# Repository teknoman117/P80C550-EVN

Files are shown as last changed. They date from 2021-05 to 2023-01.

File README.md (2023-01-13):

P80C550-EVN (Rev 1.01)
====================

The P80C550-EVN is a small 8051 single board computer designed around the notion of sourcing the major components from the random collection of electronics I've accumulated over the years. It started as a breadboard computer I built after being inspired to resume my electronics hobby after watching Ben Eater's YouTube series. After carting the breadboard computer around enough for the wires to start randomly loosening, I figured I might as well make a proper PCB for the project.

Features
--------
- CPU: P80C550 @ 11.0592 MHz
- 32 KiB ROM
- 32 KiB SRAM
- Expansion Bus
- HD44780 LCD connector
- 8x 8 bit ADC channels (from CPU)
- AM85C30 Dual UART or SDLC controller
- PCF8584 I2C controller
- MC146818 RTC and RAM with battery backup
- Runs off 5V, or 7V to 18V
- Configurable battery saver with CPU interrupt

Revision History
----------------
Revision 1.0
  - First Board Produced
  - Design and/or Production Errors
    - MAX693 RST signal (active-high) is open collector. This was not mentioned in the chip's datasheet, therefore no pull-up was designed into the board. [#1](https://github.com/teknoman117/P80C550-EVN/issues/1)
    - MAX693 ~RST signal (active-low, wired-OR) does not propagate to RST (active-high). Pushing the reset button will reset only the peripherals and not the CPU. [#2](https://github.com/teknoman117/P80C550-EVN/issues/2)

Revision 1.01
  - Disconnects the non-inverted RST signal from the MAX693
  - Add BSS84 P-Channel MOSFET to invert the ~RST signal. The P80C550 has an internal 50k to 300k pulldown resistor and the ~RST signal is current limited, so no additional components are required other than the MOSFET.

The Hardware
============

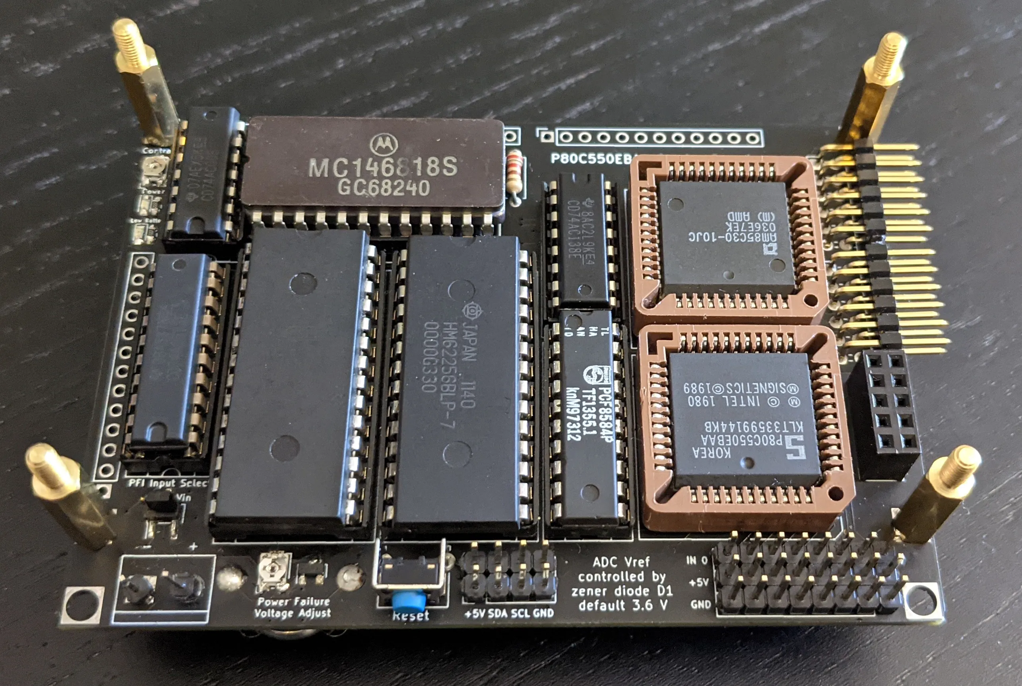
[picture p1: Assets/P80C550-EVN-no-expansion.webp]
Assembled Without Expansion Headers


## Processor

The CPU is a ROM-less CMOS 8051 microcontroller made by Signetics in the late 1980's. The only major differences from the original are that the Signetics part integrates an 8 bit analog to digital converter (with an 8 channel mux on Port 1), a programmable watchdog timer, and is built on a CMOS process. By nature of being ROM-less, the majority of the I/O ports must be used for the external bus interface (Port 2 = A8..15, Port 0 = AD0..7, Port 3.6 and 3.7 are the ~RD and ~WR signals). This is both good and bad, as we must use extra chips to get GPIO functions, but allows us to use far more than the 2K/4K/8K of ROM the 8051 could be ordered with and the 128 bytes of internal RAM. You can also use EEPROM or Flash for code storage, which is much nicer than needing to pick up an EPROM eraser.

## Memory Map

The memory for the board is provided via two 28 pin JEDEC compliant memory sockets supporting up to 32 KiB each. The left socket is for the ROM and the right socket is for the external data memory. Typically, an SRAM would be installed into the data socket, but this could also be a ROM or Flash device (such as AT29Cxx) if memory beyond the 128 byte internal RAM and 50 byte RTC/CMOS RAM is not required. Both sockets are mapped in the lower half of their respective address spaces (ROM in lower 32 KiB of CODE memory and the RAM in the lower 32 KiB of XDATA memory).

The onboard peripherals are mapped in the 8 KiB of address space following the XDATA memory as 1 KiB chunks. This may seem wasteful, but it allows using a single '138 3-to-8 decoder for peripheral chip selects (active high enable is A15, active low enables are A14 and A13. A12 -> A10 are then used for the select input).

| Code Address | Description |
| --- | --- |
| 0000h -> 7FFFh | 32 KiB ROM socket (by default - see [Expansion](#expansion)) |
| 8000h -> FFFFh | **unused**  |

| Data Address | Description |
| --- | --- |
| 0000h -> 7FFFh | 32 KiB XDATA socket |
| 8000h | [Power Status Register](#power-status-register) |
| 8400h -> 8FFFh | **unused** |
| 9000h -> 903Fh | [RTC](#rtc) |
| 9400h -> 9403h | [UART / SDLC](#uart--sdlc) |
| 9800h -> 9801h | [I2C controller](#i2c) |
| 9C00h -> 9C01h | [LCD](#lcd) |
| A000h -> FFFFh | **unused** |

## Interrupts

The P80C550 has two external interrupt lines which can either be falling edge triggered or low level triggered. There is an internal pullup resistor on the CPU and peripherals with open collector interrupt outputs can be wire-OR'd together on the same interrupt line.

| Interrupt | Devices |
| --- | --- |
| EX0 | Power Fault, RTC, I2C  |
| EX1 | UART / SDLC |

## Power and Battery Saver

The board can either be powered directly via the 5V rail, or by a 7V to 18V terminal block, which is regulated to 5V by an AP62150WU-7 buck regulator. The input voltage range means the board can be safely powered by
- 5 to 12 AA(A) batteries
- 6 to 12 cell NiMH batteries
- 2 to 4 cell Li-ion or Li-Poly batteries

There is also a holder for an *optional* CR1216, CR1220, or CR1225 3V coin cell to power the RTC. If omitted, RTC and CMOS state will be lost on power-off. A CR1216 is good for at least 2 months (and counting).

A MAX693 microprocessor supervisor is used to manage the power-on reset delay, the RTC backup power, a low power fault signal, and provide 5V rail undervoltage protection.

A potentiometer is provided to configure the low power threshold. A jumper ("PFI Input Select") is provided to select whether the source voltage is provided from the Vin terminal block or the 5V rail. The former is used in battery powered or other scenarios using the input regulator and the latter is used when the 5V rail is directly driven. A 5.1V zener diode protects from accidental overvoltage on the voltage reference inputs.

The MAX693 will report a low power fault when the reference input drops below **1.3V**. By default, this will trigger the EX0 interrupt on the P80C550. A single bit register ([Power Status Register](#power-status-register)) is provided to check the status of the power fault output of the MAX693 and to mask the interrupt it generates.

For scenarios directly powering the 5V rail, the voltage divider should be configured to output 1.444V at 5V. This will trigger the lower power fault if the rail drops to 4.5V, which is the minimum safe CPU operating voltage. The MAX693 will hold the CPU in a reset state if the 5V rail drops further to 4.4V.

In Vin powered scenarios, the AP62150WU-7 buck regulator will shut down when the reference input drops below **1.2V** and completely cut power to the board. The voltage divider should be configured such that power is cut when the voltage drops to the minimum voltage of your battery, or the minimum voltage of the regulator (about 6.5V).

To determine the output voltage of the voltage divider at a specific input voltage given a target cutoff voltage, use the following formula:

 > Vout = Vin * (1.2V / Vcutoff);

Vin is the current input voltage and Vcutoff is the desired voltage for the regulator to shut off. Vout is the voltage that the voltage divider should be configured to output at that input voltage. See the example configurations below. The emphasis on maximum voltages is to ensure you are aware that "fresh off the charger" batteries have a notably higher voltage than their nominal voltage (which they will drop to quickly), so be aware of this when tuning the cutoff reference.

### Example Voltage Divider Configurations
- Directly powering the 5V rail
  - PFI Input Select: 5V rail
  - Vcutoff = 4.5V (minimum **cpu** voltage)
  - Vout = **5V** * (1.3V / 4.5V) = 1.444V
    - Low Power Fault at 4.5V on 5V rail
    - CPU held in reset at 4.4V on 5V rail

- Li-Ion or Li-Poly Batteries (per cell: 4.2V maximum, 3.7V nominal, and 3.0V minimum)
  - PFI Input Select: Vin
  - 2 cell battery (8.4V maximum, 7.4V nominal, 6V minimum)
    - Vcutoff = 6.5V (minimum **regulator** voltage)
    - Vout = **8.4V** * (1.2V / 6.5V) = 1.550V
    - Vout = **7.4V** * (1.2V / 6.5V) = 1.366V
      - Low Power Fault at 7.04V on Vin (~12% charge)
      - Power cutoff at 6.5V on Vin (~7% charge)
  - 3 cell battery (12.6V maximum, 11.1V nominal, 9V minimum)
    - Vcutoff = 9V (minimum **battery** voltage)
    - Vout = **12.6V** * (1.2V / 9V) = 1.680V
    - Vout = **11.1V** * (1.2V / 9V) = 1.480V
      - Low Power Fault at 9.75V on Vin (~7% charge)
      - Power cutoff at 9V on Vin (~5% charge)
  - 4 cell battery (16.8V maximum, 14.8V nominal, 12V minimum)
    - Vcutoff = 12V (minimum **battery** voltage)
    - Vout = **16.8V** * (1.2V / 12V) = 1.680V
    - Vout = **14.8V** * (1.2V / 12V) = 1.480V
      - Low Power Fault at 13V on Vin (~7% charge)
      - Power cutoff at 12V on Vin (~5% charge)

- NiMH Batteries (per cell: 1.5V maximum, 1.2V nominal, and 1.0V minimum)
  - PFI Input Select: Vin
  - 7 cell battery (10.5V maximum, 8.4V nominal, 7.0V minimum)
    - Vcutoff = 7V (minimum **battery** voltage)
    - Vout = **10.5V** * (1.2 / 7V) = 1.800V
    - Vout = **8.4V** * (1.2 / 7V) = 1.440V
      - Low Power Fault at 7.58V on Vin (~5% charge)
      - Power cuttoff at 7V on Vin (~0% charge)

### Power Status Register
- Address: 8000h
- Read: Bit 7 is the ~PFO (Power Fault) line from the MAX 693 Supervisor
  - 0 = Low Voltage
  - 1 = Nominal Voltage
- Write: Bit 7 is the ~PFO (Power Fault) interrupt mask
  - 0 = Enable PFO interrupt
  - 1 = Disable PFO interrupt
- Bits 0 -> 6 undefined

## UART / SDLC

The AM85C30 "Enhanced Serial Communications Controller" can function as a UART or as an SDLC/HDLC controller. In UART mode, there is a 3 byte RX FIFO, but no TX FIFO. The SDLC/HDLC mode adds a 10 entry frame status FIFO, but the data FIFOs remain the same. The chip is intended to be used with a DMA engine, but this does not exist on the 8051 platform. If a deeper FIFO is required, there is a more modern (less old?) drop-in compatible version available called the Z85230, which appears to still in production. It adds a 4 byte TX FIFO and increases the RX FIFO to 8 bytes from 3 bytes.

| Data Address | Description |
| --- | --- |
| 9400h | Channel B - Control |
| 9401h | Channel B - Data |
| 9402h | Channel A - Control |
| 9403h | Channel A - Data |

## I2C

The PCF8584 is an I2C controller supporting a 100 KHz SCL frequency in either master or slave mode.

| Data Address | Description |
| --- | --- |
| 9800h | Register Access  |
| 9801h | Control |

## RTC

The RTC is the classic MC146818 chip that was present in the PC/AT that defined the pinout and register layout that later parts such as the Dallas DS1285, DS12885, and DS1685 use. No special battery input, no integrated oscillator, etc. The MAX693 is used to avoid needing the diode setup specified in the manual. 

| Data Address | Description |
| --- | --- |
| 9000h | Seconds |
| 9001h | Seconds (Alarm) |
| 9002h | Minutes |
| 9003h | Minutes (Alarm) |
| 9004h | Hours |
| 9005h | Hours (Alarm) |
| 9006h | Day of Week |
| 9007h | Day of Month |
| 9008h | Month |
| 9009h | Year |
| 900Ah | Register A |
| 900Bh | Register B |
| 900Ch | Register C |
| 900Dh | Register D |
| 900Eh -> 903Fh | 50 bytes of Battery Backed RAM |

## LCD

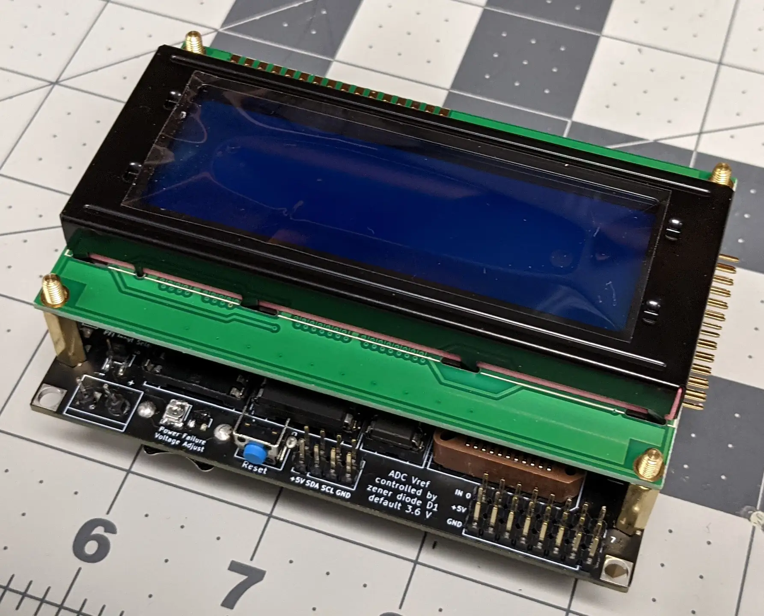
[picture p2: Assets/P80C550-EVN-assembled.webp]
Assembled With LCD


Any LCD module compatible with the 16 pin HD44780 header may be used. The mounting holes are spaced for the popular LCD2004A module (20x4 characters) that can be found pretty much everywhere.

| Data Address | Description |
| --- | --- |
| 9C00h | LCD - Control |
| 9C01h | LCD - Data |

## PCB
| Front Side | Back Side |
| --- | --- |
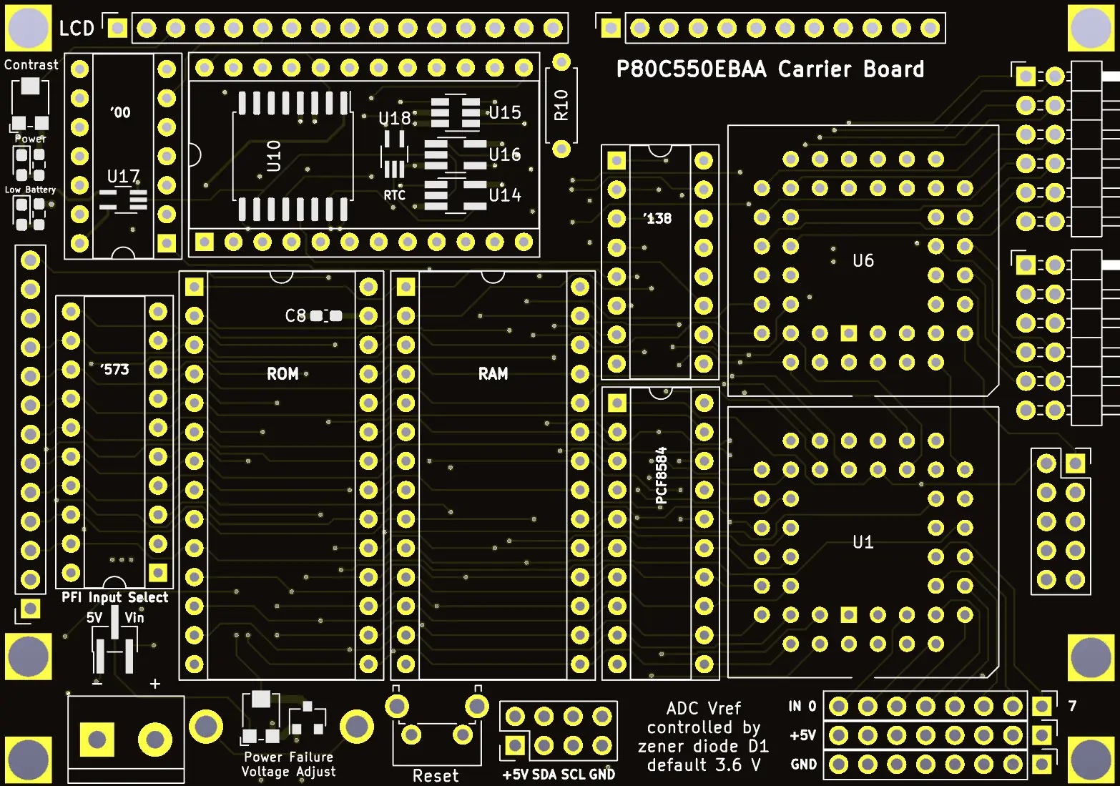
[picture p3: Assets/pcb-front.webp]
Front
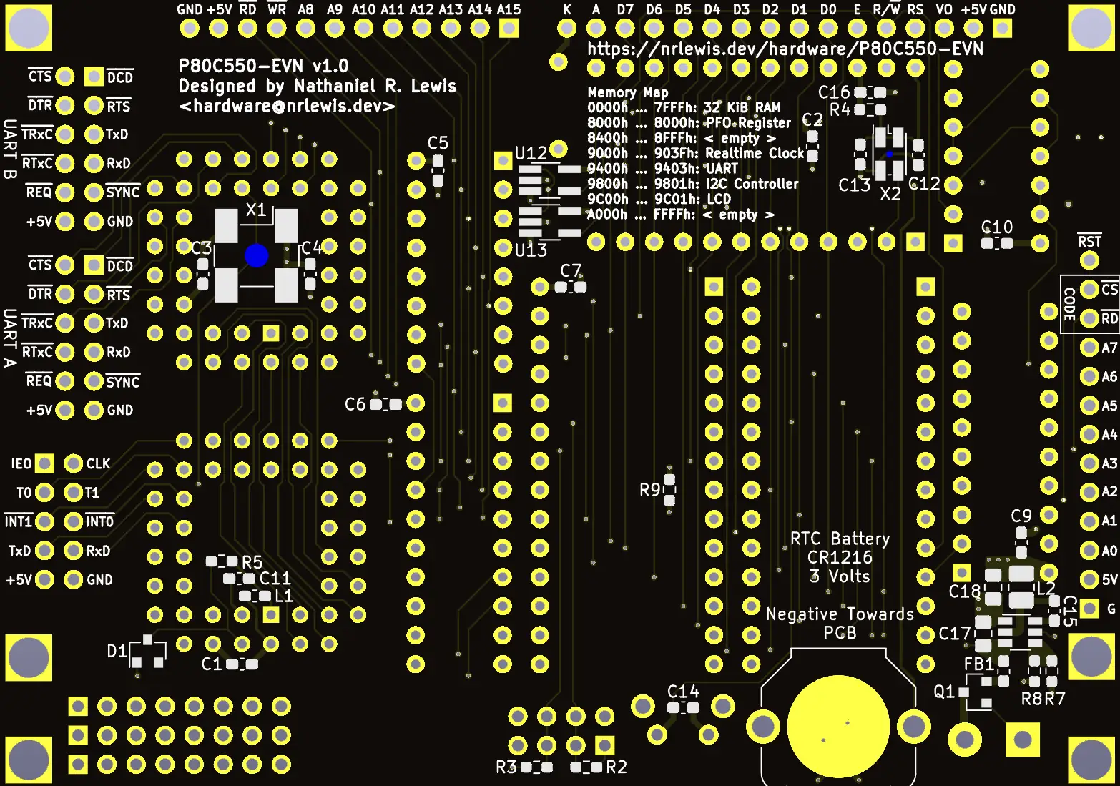
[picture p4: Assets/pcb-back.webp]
Back
|  |  |

| Layout (Power Planes Not Shown) |
| ---------------------------------- |
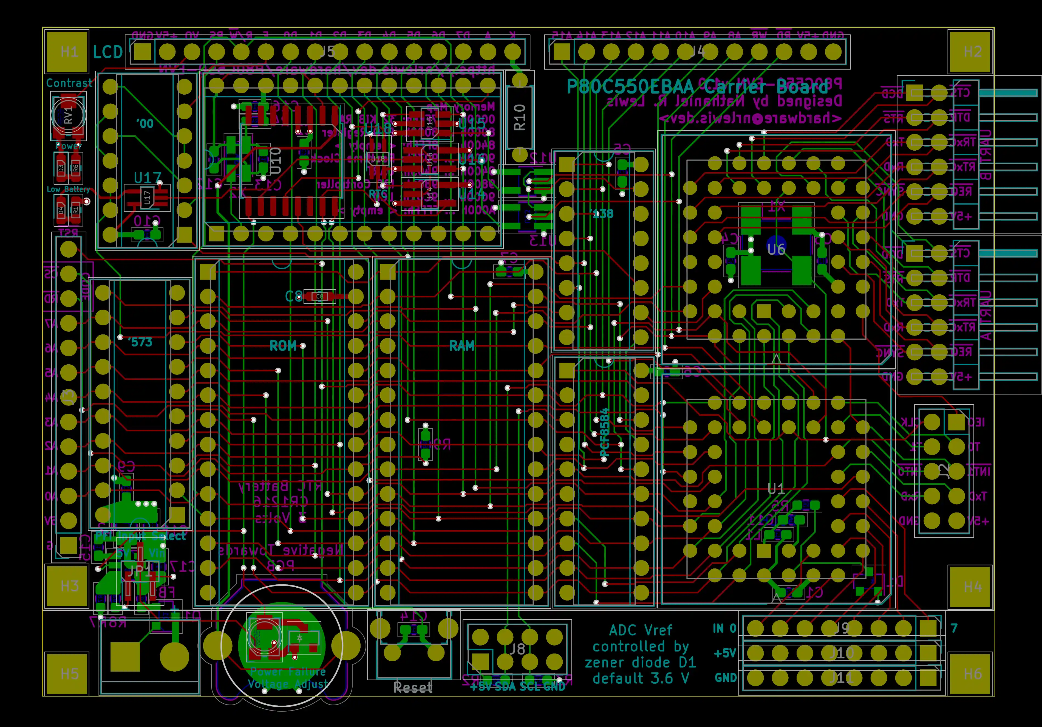
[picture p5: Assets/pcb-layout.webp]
Layout
|  |

The PCB is a 98 mm by 69 mm, 4-layer board (2 signal layers, one +5V plane, and one ground plane) following the design rules for the low cost JLCPCB 4-layer process. Using 4 layers made the routing far easier, as I didn't have to worry about getting power in and around all of the signal traces. At time time of writing, 5 boards using Leaded HASL and a green PCB material is $8 (USD). Switching to ENIG-RoHS increases the price to $23.40 (USD) for 5 boards. 10 boards is $29 (USD), as they seemingly charge a flat rate for switching to ENIG on small orders. I also opted for FR4 TG155 because it's more tolerant to hot air soldering.

To order, you can contact me at [hardware@nrlewis.dev](mailto:hardware@nrlewis.dev) and see if I have any laying around, or you can send the gerber files (attached to release tags) to your board house of choice. JLCPCB is my recommendation, as it seems that they have a lower 4-layer board tier available. PCBWay seems good as well, but their 4-layer process is a bit overkill for this board.

The smallest components on the PCB are 0603 passives. These are the smallest size I'm comfortable hand soldering. Call me crazy, but I assembled this whole board using a Weller WE1010NA soldering station with a (small point) chisel tip, flux core solder, a flux pen, some solder wick, and a pair of tweezers from an iFixit kit. Apply flux generously, hold the components onto the pads with tweezers, hold your breath, and apply solder.

## Expansion

All of the major bus signals are broken out to stackable headers to allow for stacked expansion boards.

### ROM Expansion

The ROM read signal (~CODE_RD) and chip select (~CODE_CS) are broken out to the address low-byte header. The ~CODE_CS pin has a pulldown to keep the ROM enabled when no expansion boards are installed. The main idea behind these signals is to enable the creation of a self-programming expansion. By default, the ROM socket occupies both the lower and upper 32 KiB of the code address space, as the chip select is always enabled and A15 is ignored. A self programming module would allow the onboard ROM be either relocated or disabled when switching to an external memory.

#### Address Low-Byte Header

| Pin | Description |
| --- | --- |
| 1 | GND |
| 2 | +5V |
| 3 | A0 |
| 4 | A1 |
| 5 | A2 |
| 6 | A3 |
| 7 | A4 |
| 8 | A5 |
| 9 | A6 |
| 10  | A7 |
| 11  | ~CODE_RD |
| 12  | ~CODE_CS |
| 13  | ~RST |

#### Address High-Byte Header

| Pin | Description |
| --- | --- |
| 1 | A15 |
| 2 | A14 |
| 3 | A13 |
| 4 | A12 |
| 5 | A11 |
| 6 | A10 |
| 7 | A9 |
| 8 | A8 |
| 9 | ~WR |
| 10  | ~RD |
| 11  | +5V |
| 12  | GND |

#### LCD Header

| Pin | Description  |
| --- | --- |
| 1 | GND |
| 2 | +5V |
| 3 | LCD_VO |
| 4 | A0 |
| 5 | ~WR |
| 6 | LCD_E |
| 7 | D0 |
| 8 | D1 |
| 9 | D2 |
| 10  | D3 |
| 11  | D4 |
| 12  | D5 |
| 13  | D6 |
| 14  | D7 |
| 15  | LCD_A (+5V)  |
| 16  | LCD_K |

#### CPU Peripheral Header

| Pin | Description |
| --- | --- |
| 1 | UART_IEO |
| 2 | CLK (11.0592 MHz) |
| 3 | P3.4 - T0 |
| 4 | P3.5 - T1 |
| 5 | P3.3 - ~INT1 |
| 6 | P3.2 - ~INT0 |
| 7 | P3.1 - TxD |
| 8 | P3.0 - RxD |
| 9 | +5V |
| 10  | GND |

#### ADC Header

| Pin | Description  |
| --- | --- |
| 1 | P1.0 (ADC 0) |
| 2 | P1.1 (ADC 1) |
| 3 | P1.2 (ADC 2) |
| 4 | P1.3 (ADC 3) |
| 5 | P1.4 (ADC 4) |
| 6 | P1.5 (ADC 5) |
| 7 | P1.6 (ADC 6) |
| 8 | P1.7 (ADC 7) |

#### UART Headers

| Pin | Description |
| --- | --- |
| 1 | DCD |
| 2 | CTS |
| 3 | RTS |
| 4 | DTR |
| 5 | TX |
| 6 | TX Clock |
| 7 | RX |
| 8 | RX Clock |
| 9 | SYNC |
| 10  | REQ |
| 11  | GND |
| 12  | +5V |

## Datasheets

[P80C550EBAA - DigChip](https://www.digchip.com/datasheets/download_datasheet.php?id=741162&part-number=P80C550EBAA)

[MAX693 - Maxim](https://datasheets.maximintegrated.com/en/ds/MAX690-MAX695.pdf)

[AM85C30 (1) - ChipDB](http://datasheets.chipdb.org/AMD/07513.pdf)

[AM85C30 (2) - Rockby](https://www.rockby.com.au/DSheets/26719.pdf)

[PCF8584 - NXP](https://www.nxp.com/docs/en/data-sheet/PCF8584.pdf)

[MC146818 - NXP](https://www.nxp.com/docs/en/data-sheet/MC146818.pdf)

[LCD2004A - Beta-eStore](https://www.beta-estore.com/download/rk/RK-10290_410.pdf)

## Background

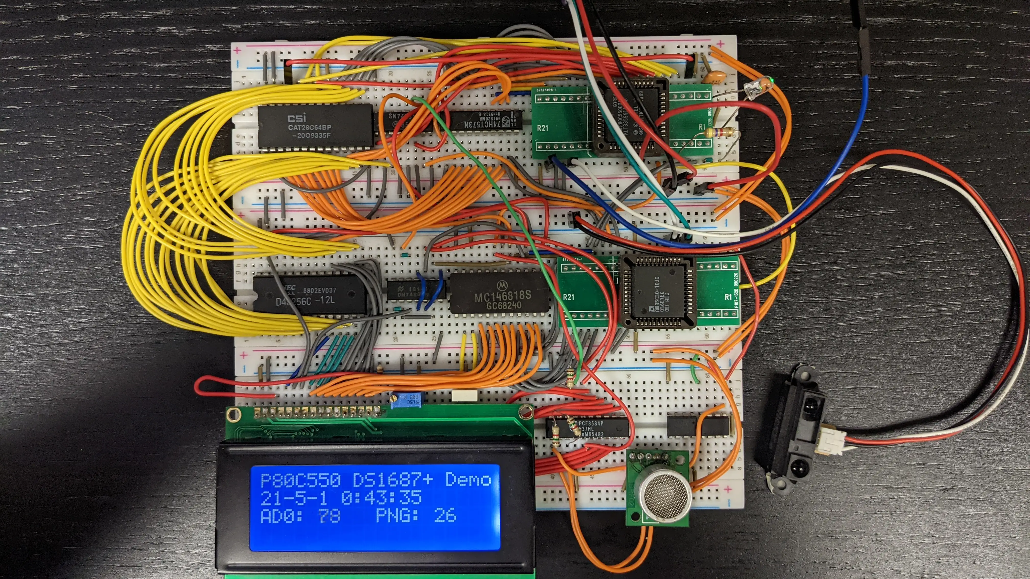
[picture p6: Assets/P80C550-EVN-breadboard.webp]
Breadboard Computer


The design goal was for the major components to be sourced from the collection of random electronics I've accumulated over the years - hence a board built around archaic parts newly created in 2021.

The peripherals are straight out of a 1980's PC builder's kit. I think it was 2003 when I received the core parts of this board. I was a member of Chibots in Chicago as a kid and I picked them up during the regular "I'm not taking this back home with me" parts dump / swap meet at the end of club meetings. I ended up with a tubes of 8051 controllers, MAX693 microprocessor supervisors, AM85C30 Dual UARTs / SDLC / HDLC controllers, MC146818 RTC/RAMs (used on PC/AT), and some engineering sample RS232 to TTL level shifters (XC prefix Motorola parts). I have to imagine the person who gave them to me had to have built a board along these lines sometime in the past. Probably with these components. I bet they didn't have the luxury of dirt-cheap 4 layer PCBs though and open source EDA tools :).

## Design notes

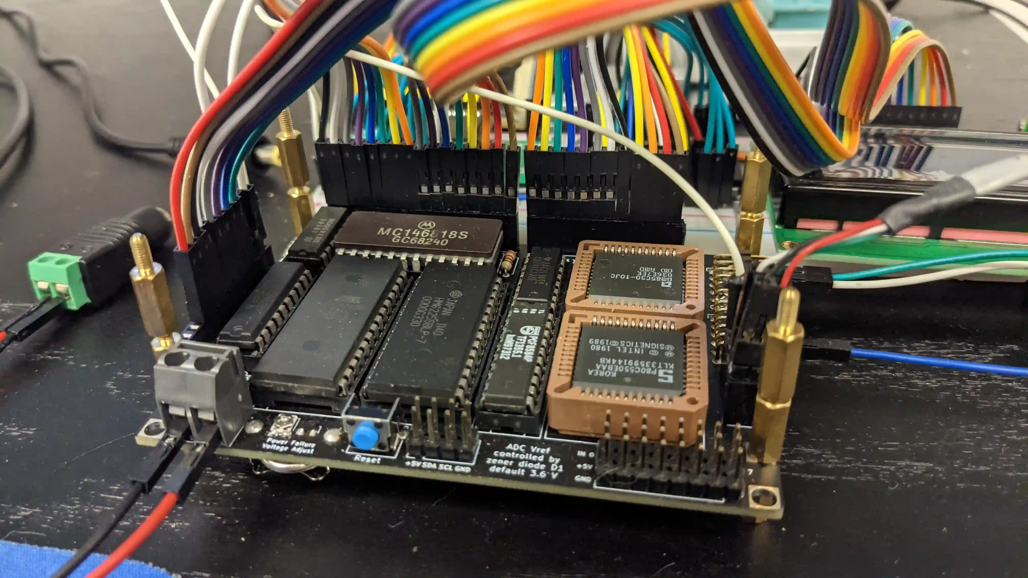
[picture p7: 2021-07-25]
Assets/P80C550-EVN-expansion.webp

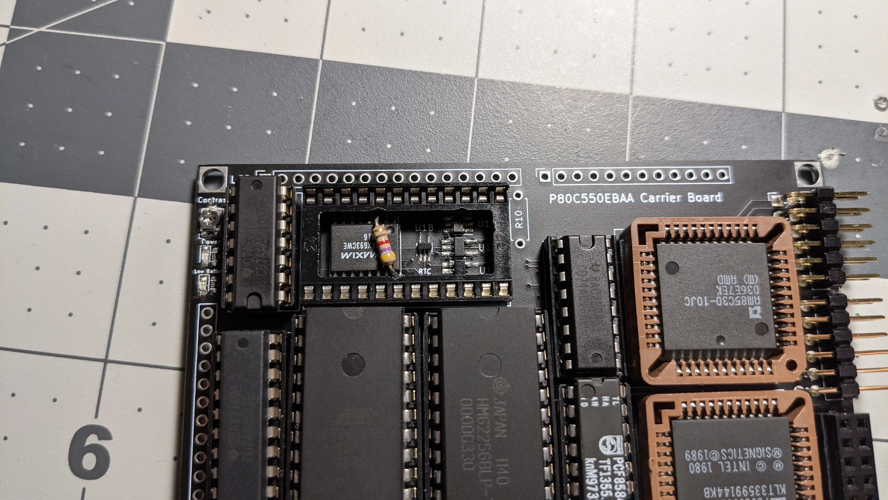
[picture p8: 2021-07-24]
Assets/P80C550-EVN-reset-bodge.webp

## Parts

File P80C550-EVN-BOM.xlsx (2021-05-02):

Component | Quantity | Quantity 5x | Part Name | Digikey Part Number | Digikey Website Link | Manufacturer Part Number
BT1 | 1 | 5 | RTC Backup | 36-3001-ND‎ | https://www.digikey.com/product-detail/en/3001/36-3001-ND/227442 | 3001
C16 | 1 | 5 | 5.1nF | 478-06033C512JAT4ACT-ND | https://www.digikey.com/en/products/detail/avx-corporation/06033C512JAT4A/1599493 | 06033C512JAT4A
C17 | 1 | 5 | 10uF | 587-2985-1-ND | https://www.digikey.com/en/products/detail/taiyo-yuden/TMK212BBJ106KG-T/2714163 | TMK212BBJ106KG-T
C18 | 1 | 5 | 22uF | 587-5464-1-ND | https://www.digikey.com/en/products/detail/taiyo-yuden/LMK212BBJ226MG-T/7067049 | LMK212BBJ226MG-T
C1 C2 C3 C4 C5 C6 C7 C8 C9 C10 C11 C12 C13 C14 C15 | 15 | 75 | 0.1uF | 445-1316-1-ND‎ | https://www.digikey.com/product-detail/en/C1608X7R1E104K080AA/445-1316-1-ND/567697 | C1608X7R1E104K080AA
D1 | 1 | 5 | 3.6V (zener) | 1727-5033-1-ND‎ | https://www.digikey.com/product-detail/en/BZX84-C3V6%2c215/1727-5033-1-ND/2531614 | BZX84-C3V6,215
D1 (alt) | 1 | 5 | 3.3V (zener) | 1727-2129-1-ND | https://www.digikey.com/en/products/detail/nexperia-usa-inc/BZX84-C3V3-235/1156089 | BZX84-C3V3,235
D2 | 1 | 5 | 5.1V (zener) | 1727-2130-1-ND‎ | https://www.digikey.com/product-detail/en/BZX84-C5V1%2c235/1727-2130-1-ND/5221774/?itemSeq=362662134 | BZX84-C5V1,235
D3 | 1 | 5 | Blue | ‎1830-1068-1-ND‎ | https://www.digikey.com/product-detail/en/IN-S63BT5B/1830-1068-1-ND/7604710 | IN-S63BT5B
D4 | 1 | 5 | Yellow | 1830-1072-1-ND‎ | https://www.digikey.com/product-detail/en/IN-S63BTR/1830-1072-1-ND/7604714 | IN-S63BTR
FB1 | 1 | 5 | 100 @ 100 MHz | 587-1738-1-ND‎ | https://www.digikey.com/product-detail/en/FBMH1608HM101-T/587-1738-1-ND/1147063 | FBMH1608HM101-T
J1 | 1 | 5 | VIN | 1920-1323-ND | https://www.digikey.com/en/products/detail/altech-corporation/34-102/8547113 | 34.102
J2 | 1 | 5 | Signals | S7108-ND | https://www.digikey.com/en/products/detail/PPPC052LFBN-RC/S7108-ND/810245 | PPPC052LFBN-RC
J3 | 1 | 5 | Address Low | S7046-ND | https://www.digikey.com/en/products/detail/PPPC131LFBN-RC/S7046-ND/810185 | PPPC131LFBN-RC
J4 | 1 | 5 | Address High | S7046-ND | https://www.digikey.com/en/products/detail/PPPC131LFBN-RC/S7046-ND/810185 | PPPC131LFBN-RC
J5 | 1 | 5 | LCD | S7049-ND | https://www.digikey.com/en/products/detail/PPPC161LFBN-RC/S7049-ND/810188 | PPPC161LFBN-RC
J6 J7 | 2 | 10 | UART | S2111EC-06-ND | https://www.digikey.com/en/products/detail/sullins-connector-solutions/PRPC006DBAN-M71RC/2775714 | PRPC006DBAN-M71RC
J8 | 1 | 5 | I2C | S2011EC-04-ND | https://www.digikey.com/en/products/detail/sullins-connector-solutions/PRPC004DAAN-RC/2775290 | PRPC004DAAN-RC
J9 J10 J11 | 3 | 15 | Analog In | S1011EC-08-ND | https://www.digikey.com/en/products/detail/sullins-connector-solutions/PRPC008SAAN-RC/2775246 | PRPC008SAAN-RC
JP1 | 1 | 5 | PFI Select | 952-3607-ND | https://www.digikey.com/en/products/detail/harwin-inc/M50-3630342/7044022 | M50-3630342
L1 | 1 | 5 | 39uH | 712-1441-1-ND‎ | https://www.digikey.com/product-detail/en/L-14C39NJV4T/712-1441-1-ND/1914891 | L-14C39NJV4T
L2 | 1 | 5 | 4.7uH | 535-12797-1-ND | https://www.digikey.com/en/products/detail/abracon-llc/AIML-1008HC-4R7M-T/5043494 | AIML-1008HC-4R7M-T
Q1 | 1 | 5 | Si2393DS | ‎742-SI2393DS-T1-GE3CT-ND‎ | https://www.digikey.com/product-detail/en/SI2393DS-T1-GE3/742-SI2393DS-T1-GE3CT-ND/10484610 | SI2393DS-T1-GE3
R1 R2 R3 R4 R5 R6 | 6 | 30 | 2K2 ohms | 118-CR0603-FX-2201ELFCT-ND‎ | https://www.digikey.com/product-detail/en/CR0603-FX-2201ELF/118-CR0603-FX-2201ELFCT-ND/3925309 | CR0603-FX-2201ELF
R7 | 1 | 5 | 10K ohms | CR0603-FX-1002ELFCT-ND | https://www.digikey.com/en/products/detail/bourns-inc/CR0603-FX-1002ELF/3593188 | CR0603-FX-1002ELF
R8 | 1 | 5 | 52K3 ohms | CR0603-FX-5232ELFCT-ND | https://www.digikey.com/en/products/detail/bourns-inc/CR0603-FX-5232ELF/3784077 | CR0603-FX-5232ELF
R9 | 1 | 5 | 680 ohms | 118-CR0603-JW-681ELFCT-ND‎ | https://www.digikey.com/product-detail/en/CR0603-JW-681ELF/118-CR0603-JW-681ELFCT-ND/3925375 | CR0603-JW-681ELF
R10 | 1 | 5 | 220 ohms
RV1 RV2 | 2 | 10 | 20K | TC33X-1-203ECT-ND | https://www.digikey.com/en/products/detail/TC33X-1-203E/TC33X-1-203ECT-ND/9998913 | TC33X-1-203E
SW1 | 1 | 5 | Reset | CKN10909-ND | https://www.digikey.com/en/products/detail/c-k/PTS645VM39-2-LFS/3861402 | PTS645VM39-2 LFS
U1 | 1 | 5 | P80C550EBAA
U10 | 1 | 5 | MAX691xWE
U11 | 1 | 5 | AP62150WU-7 | 31-AP62150WU-7CT-ND | https://www.digikey.com/en/products/detail/diodes-incorporated/AP62150WU-7/13161380 | AP62150WU-7
U12 U13 U14 | 3 | 15 | 74VHC1G02 | MC74VHC1G02DTT1GOSCT-ND‎ | https://www.digikey.com/product-detail/en/MC74VHC1G02DTT1G/MC74VHC1G02DTT1GOSCT-ND/2120978 | MC74VHC1G02DTT1G
U15 | 1 | 5 | 74LVC1G373 | 296-18588-1-ND‎ | https://www.digikey.com/product-detail/en/SN74LVC1G373DBVR/296-18588-1-ND/857357 | SN74LVC1G373DBVR
U16 | 1 | 5 | 74VHC1G126 | M74VHC1G126DTT1GOSCT-ND‎ | https://www.digikey.com/product-detail/en/M74VHC1G126DTT1G/M74VHC1G126DTT1GOSCT-ND/3487546 | M74VHC1G126DTT1G
U17 | 1 | 5 | 74LVC1G07 | 1727-1181-1-ND‎ | https://www.digikey.com/product-detail/en/74LVC1G07GW-Q100H/1727-1181-1-ND/4311447 | 74LVC1G07GW-Q100H
U18 | 1 | 5 | 74LVC1G06 | 1727-6064-1-ND‎ | https://www.digikey.com/product-detail/en/74LVC1G06GW%2c125/1727-6064-1-ND/2753900 | 74LVC1G06GW,125
U2 | 1 | 5 | 74AC573 | 296-1379-5-ND | https://www.digikey.com/en/products/detail/CD74AC573E/296-1379-5-ND/277029 | CD74AC573E
U3 | 1 | 5 | HM62256BLP | AS6C62256-55PCN | https://www.digikey.com/en/products/detail/alliance-memory-inc/AS6C62256-55PCN/4234592 | AS6C62256-55PCN
U4 | 1 | 5 | 28C256 | AT28C256-15PU-ND | https://www.digikey.com/en/products/detail/microchip-technology/at28c256-15pu/1008506 | AT28C256-15PU
U5 | 1 | 5 | MC146818
U6 | 1 | 5 | AM85C30 | 269-3927-ND | https://www.digikey.com/en/products/detail/zilog/Z8523016VSG/928917 | Z8523016VSG
U7 | 1 | 5 | 74AHC138 | 296-4225-5-ND | https://www.digikey.com/en/products/detail/CD74AC138E/296-4225-5-ND/375864 | CD74AC138E
U8 | 1 | 5 | PCF8584
U9 | 1 | 5 | 74AC00 | 296-4214-5-ND | https://www.digikey.com/en/products/detail/CD74AC00E/296-4214-5-ND/375682 | CD74AC00E
X1 | 1 | 5 | 11.0592 MHz | SER4011CT-ND‎ | https://www.digikey.com/product-detail/en/SG7050CCN+11.059200M-HJGA3/SER4011CT-ND/5175103 | SG7050CCN 11.059200M-HJGA3
X2 | 1 | 5 | 32.768 KHz | XC1751CT-ND‎ | https://www.digikey.com/product-detail/en/ECS-327KE-TR/XC1751CT-ND/2666656 | ECS-327KE-TR
socket (U1, U6) | 2 | 10 | 44 pin socket | AE10064-ND | https://www.digikey.com/en/products/detail/assmann-wsw-components/A-CCS-044-G-T/821818 | A-CCS 044-G-T
socket (U9) | 1 | 5 | 14 pin socket | 2057-ICS-314-T-ND | https://www.digikey.com/en/products/detail/adam-tech/ICS-314-T/9832866 | ICS-314-T
socket (U7) | 1 | 5 | 16 pin socket | 2057-ICS-316-T-ND | https://www.digikey.com/en/products/detail/adam-tech/ICS-316-T/9832862 | ICS-316-T
socket (U2, U8) | 2 | 10 | 20 pin socket | 2057-ICS-320-T-ND | https://www.digikey.com/en/products/detail/adam-tech/ICS-320-T/9832868 | ICS-320-T
socket (U5) | 1 | 5 | 24 pin socket | 2057-ICS-624-T-ND | https://www.digikey.com/en/products/detail/adam-tech/ICS-624-T/9832867 | ICS-624-T
socket (U3, U4) | 2 | 10 | 28 pin socket | 2057-ICS-628-T-ND | https://www.digikey.com/en/products/detail/adam-tech/ICS-628-T/9832869 | ICS-628-T
jumper | 1 | 5 | jumper | 2057-HMSC-G-ND | https://www.digikey.com/en/products/detail/adam-tech/HMSC-G/9830451 | HMSC-G
headers (bulk) | 1 | 5 | headers | S1011EC-40-ND | https://www.digikey.com/en/products/detail/sullins-connector-solutions/PRPC040SAAN-RC/2775214 | PRPC040SAAN-RC

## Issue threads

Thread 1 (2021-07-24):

CPU is unstable and constantly resetting after power-up (Revision 1.0)

teknoman117, 2021-07-24:
After powering up the board, the CPU appears to be resetting once per second or so. Loading a program that prints out a message once and then spins forever prints the message about once per second.

teknoman117, 2021-07-24:
I've identified the root cause of the issue.

The MAX693 microprocessor supervisor in the SOIC (W) 16 package provides both an active-high (RESET) and an active-low (~RESET) signal. Most of the peripherals on the board use the inverted reset signal, however the 8051 uses the non-inverted reset signal.

It is not mentioned in the datasheet for the MAX693, but the non-inverted reset signal is actually an open collector output. I only figured this out by seeing that the drop in replacement for the MAX693 notes that the non-inverted reset is open collector.

A simple fix is to solder a resistor (I used 4k7) from the +5V rail to the non-inverted reset output. I soldered it across the top of the MAX693 from pin 3 to pin 16.

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

Closed 2023-01-13.

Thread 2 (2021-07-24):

Reset button doesn't reset the CPU (Revision 1.0)

teknoman117, 2021-07-24:
Pushing the reset button doesn't reset the CPU.

teknoman117, 2021-07-24:
This is another MAX693 related problem. The datasheet describes wired-OR'ing both devices and sources of a reset on the inverted reset output. However, a device that isn't the MAX693 pulling ~RESET low will not cause the reset event to propagate to the non-inverted reset signal. Pushing the reset button will reset the peripherals but not the CPU.

A fix for this is to cut the RST trace entirely, and connect a PNP transistor between +5V and the processor's RST pin. Connect the base to the inverted reset signal, bypassing the non-inverted signal from the MAX693 entirely.

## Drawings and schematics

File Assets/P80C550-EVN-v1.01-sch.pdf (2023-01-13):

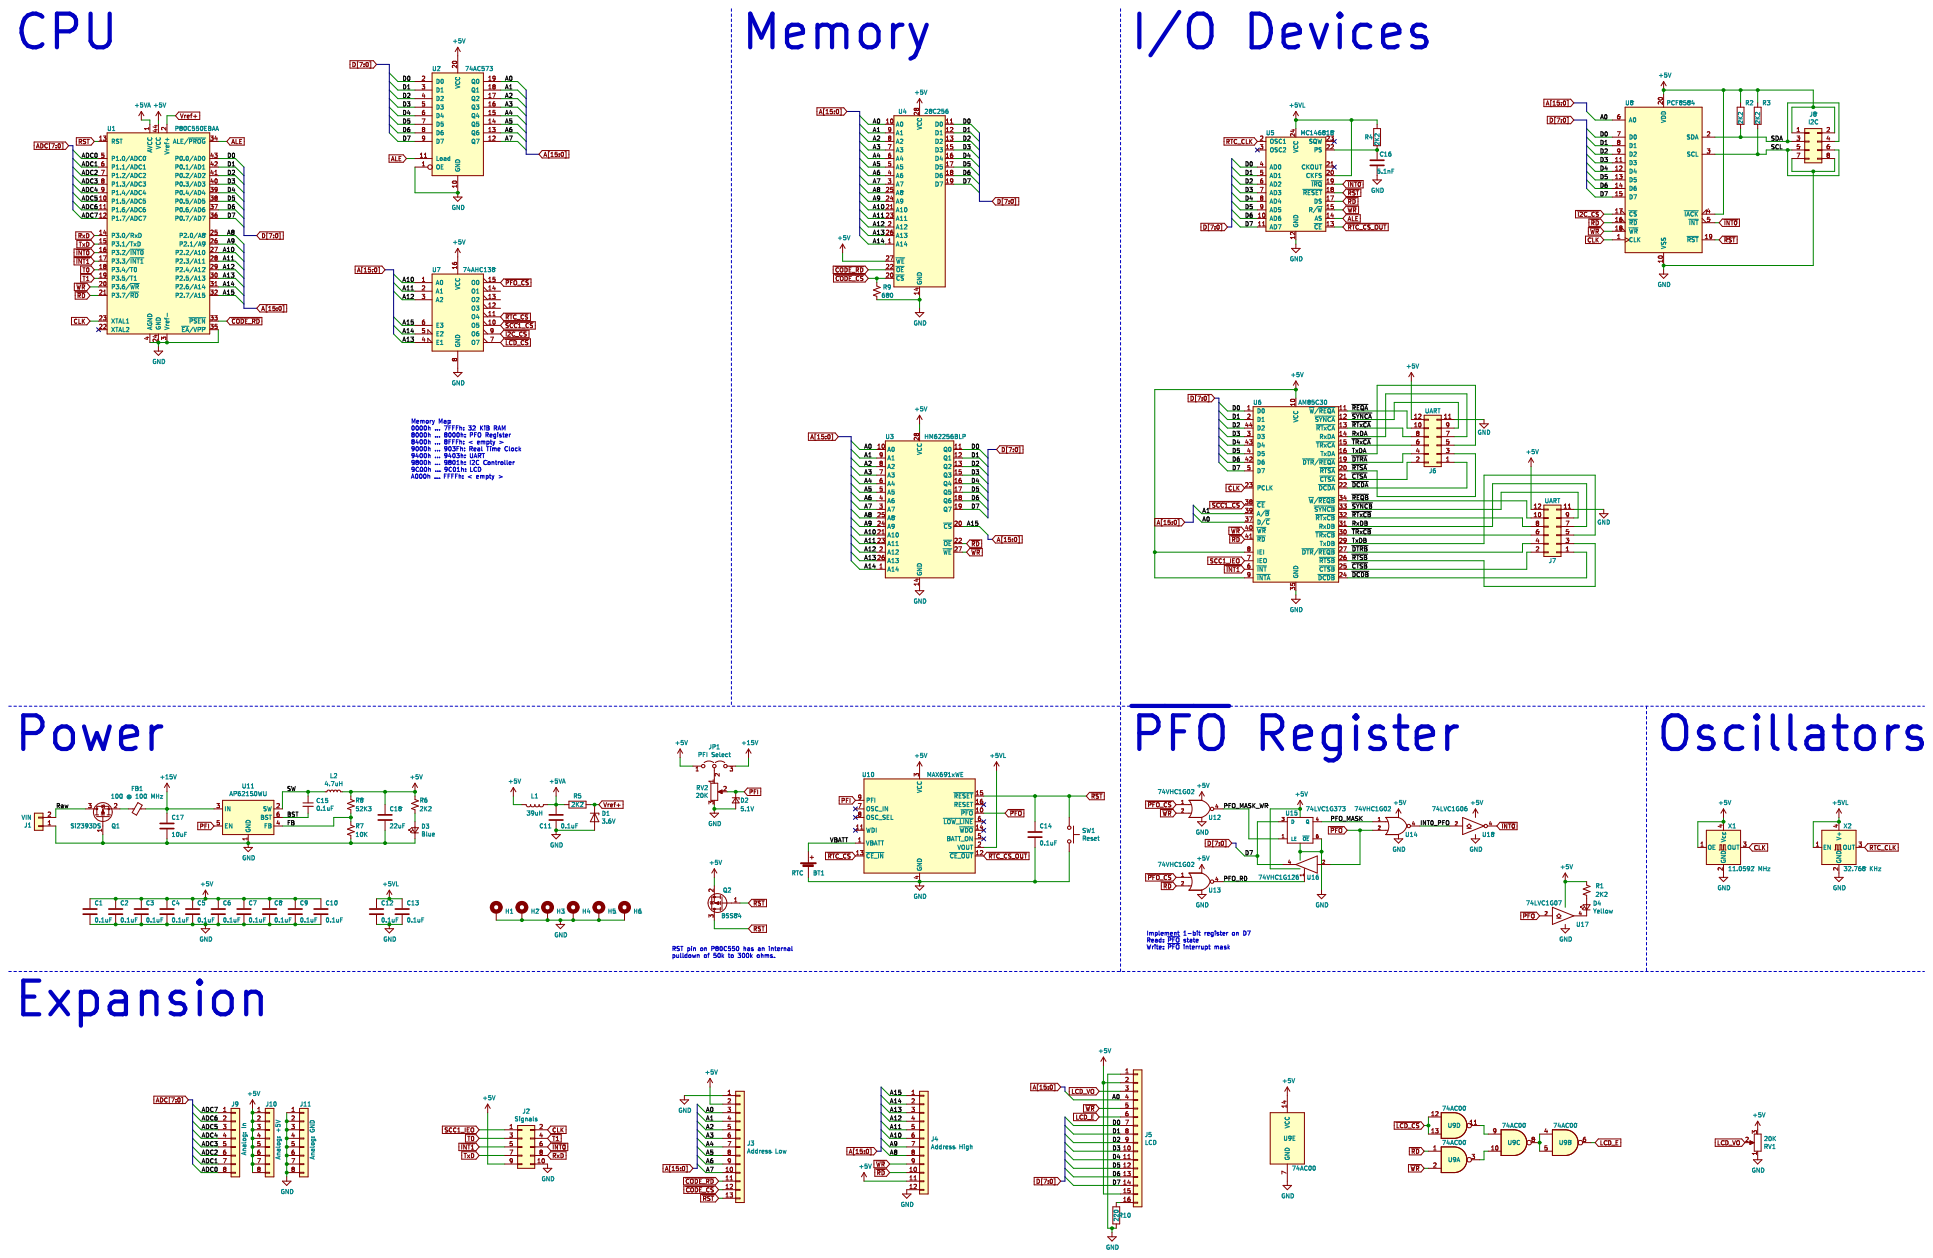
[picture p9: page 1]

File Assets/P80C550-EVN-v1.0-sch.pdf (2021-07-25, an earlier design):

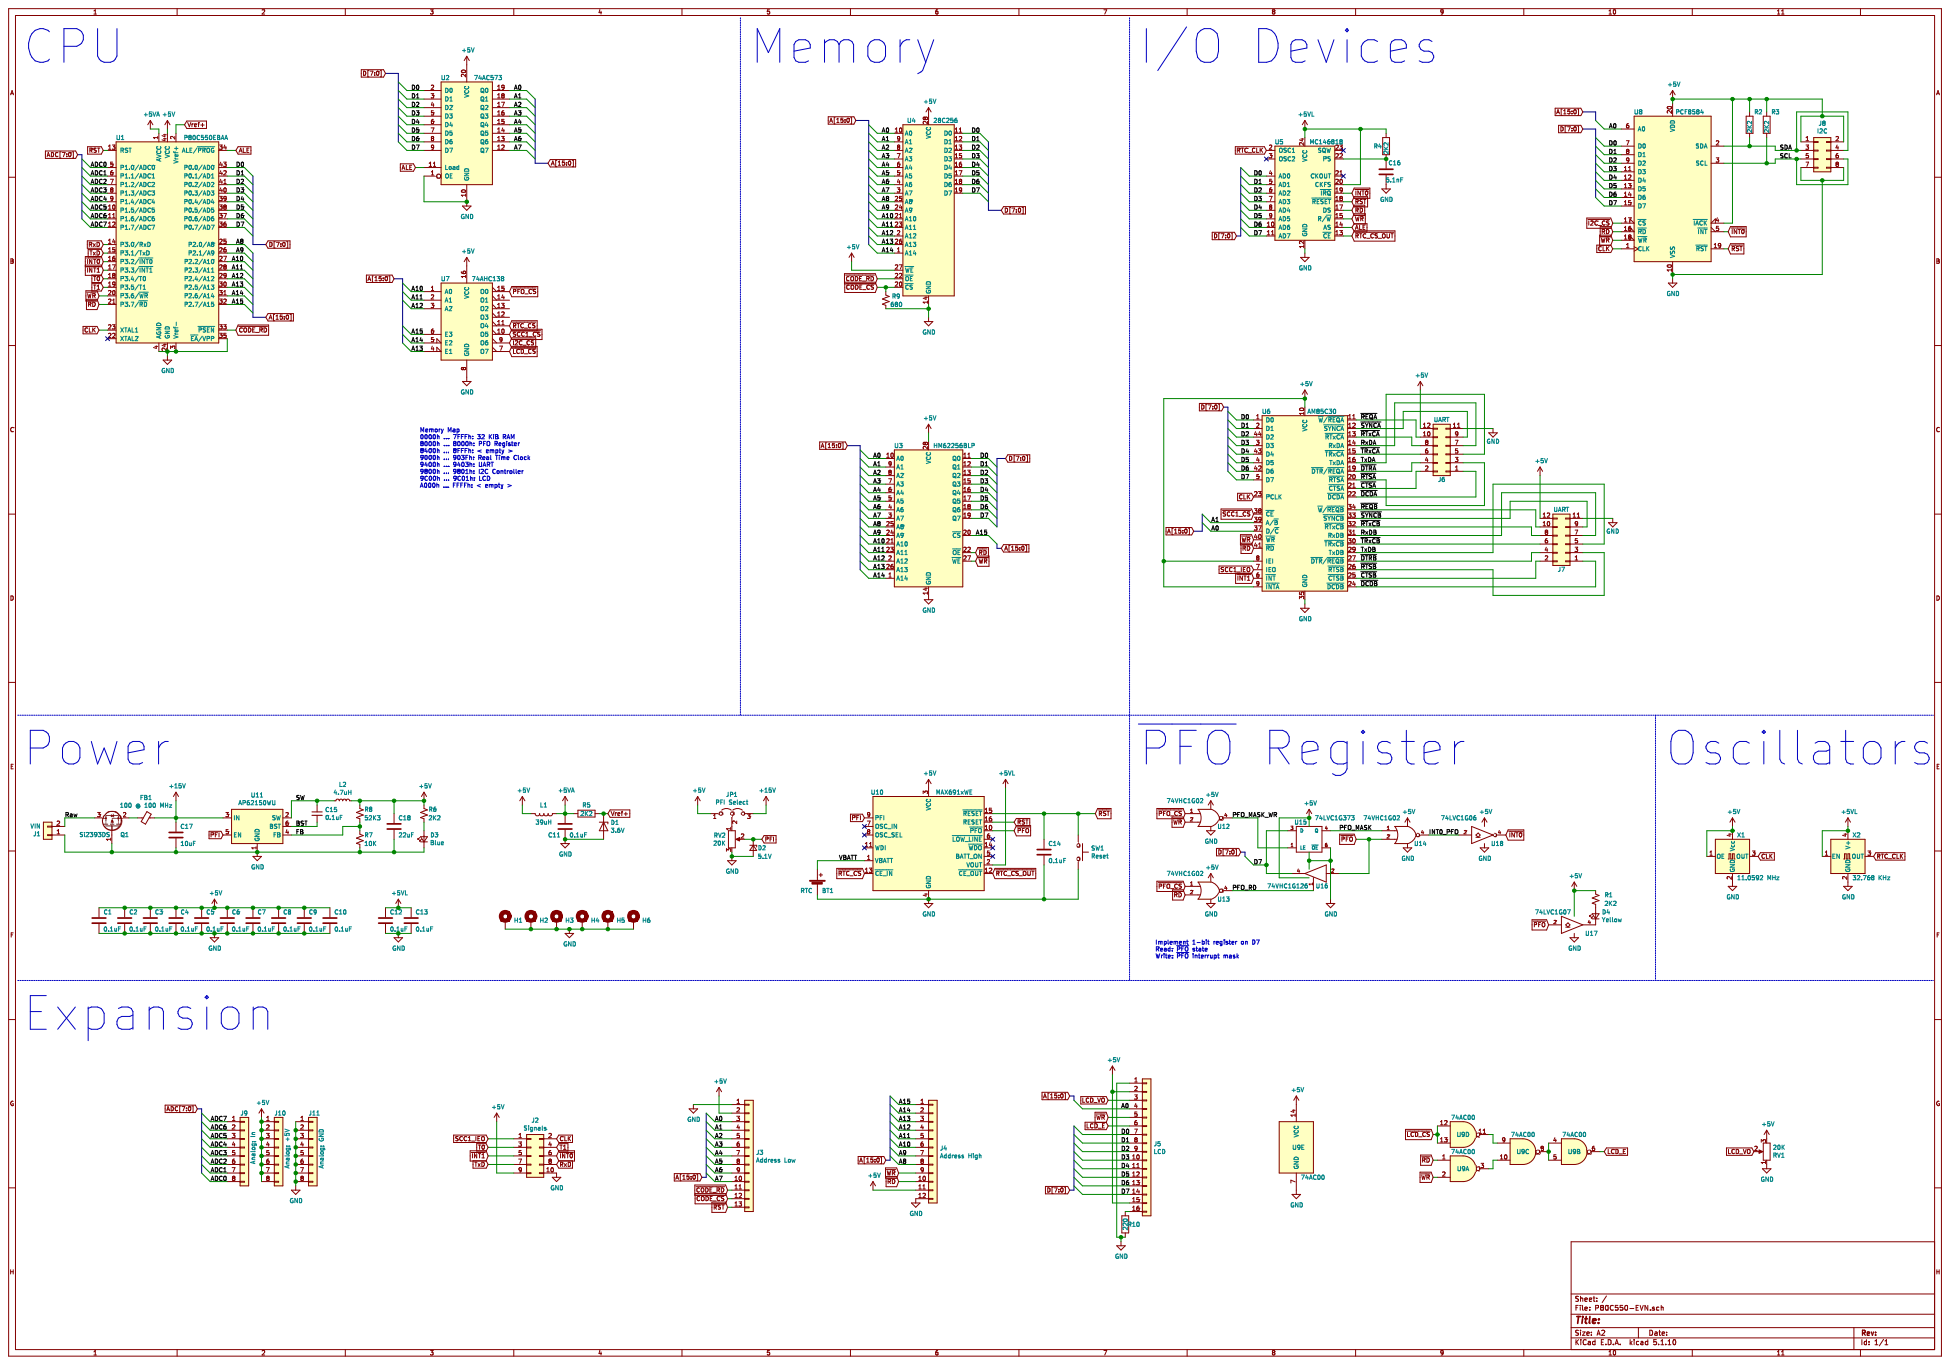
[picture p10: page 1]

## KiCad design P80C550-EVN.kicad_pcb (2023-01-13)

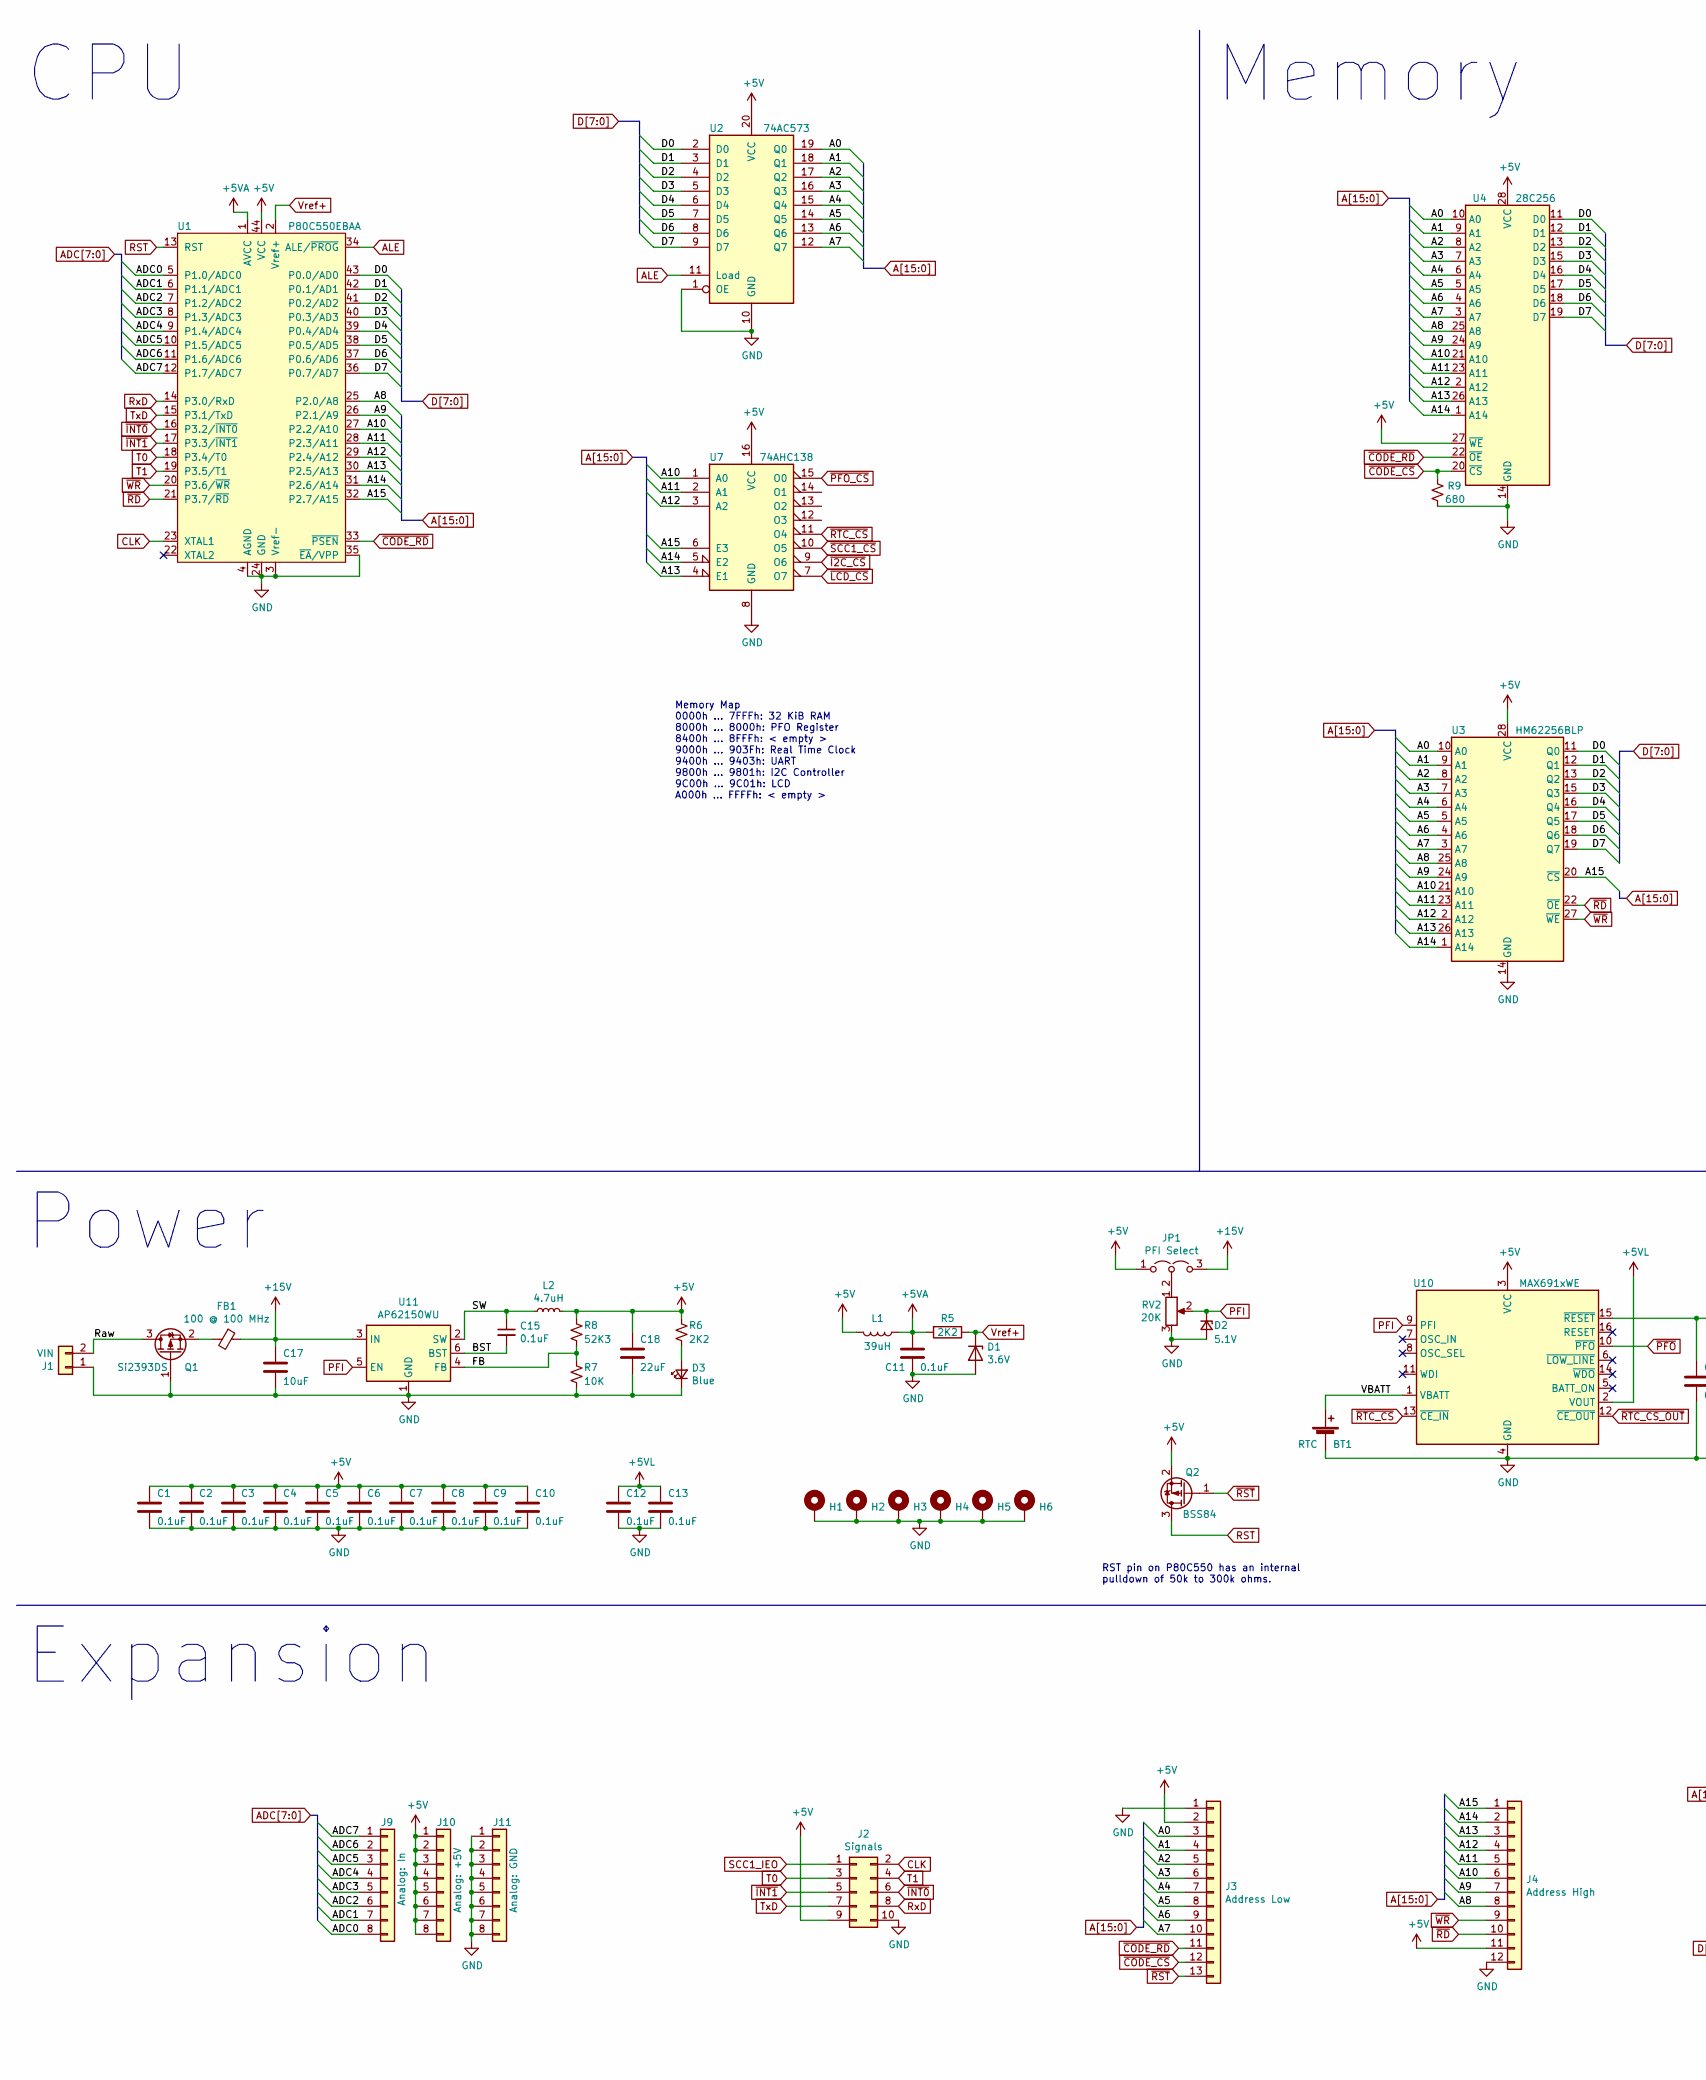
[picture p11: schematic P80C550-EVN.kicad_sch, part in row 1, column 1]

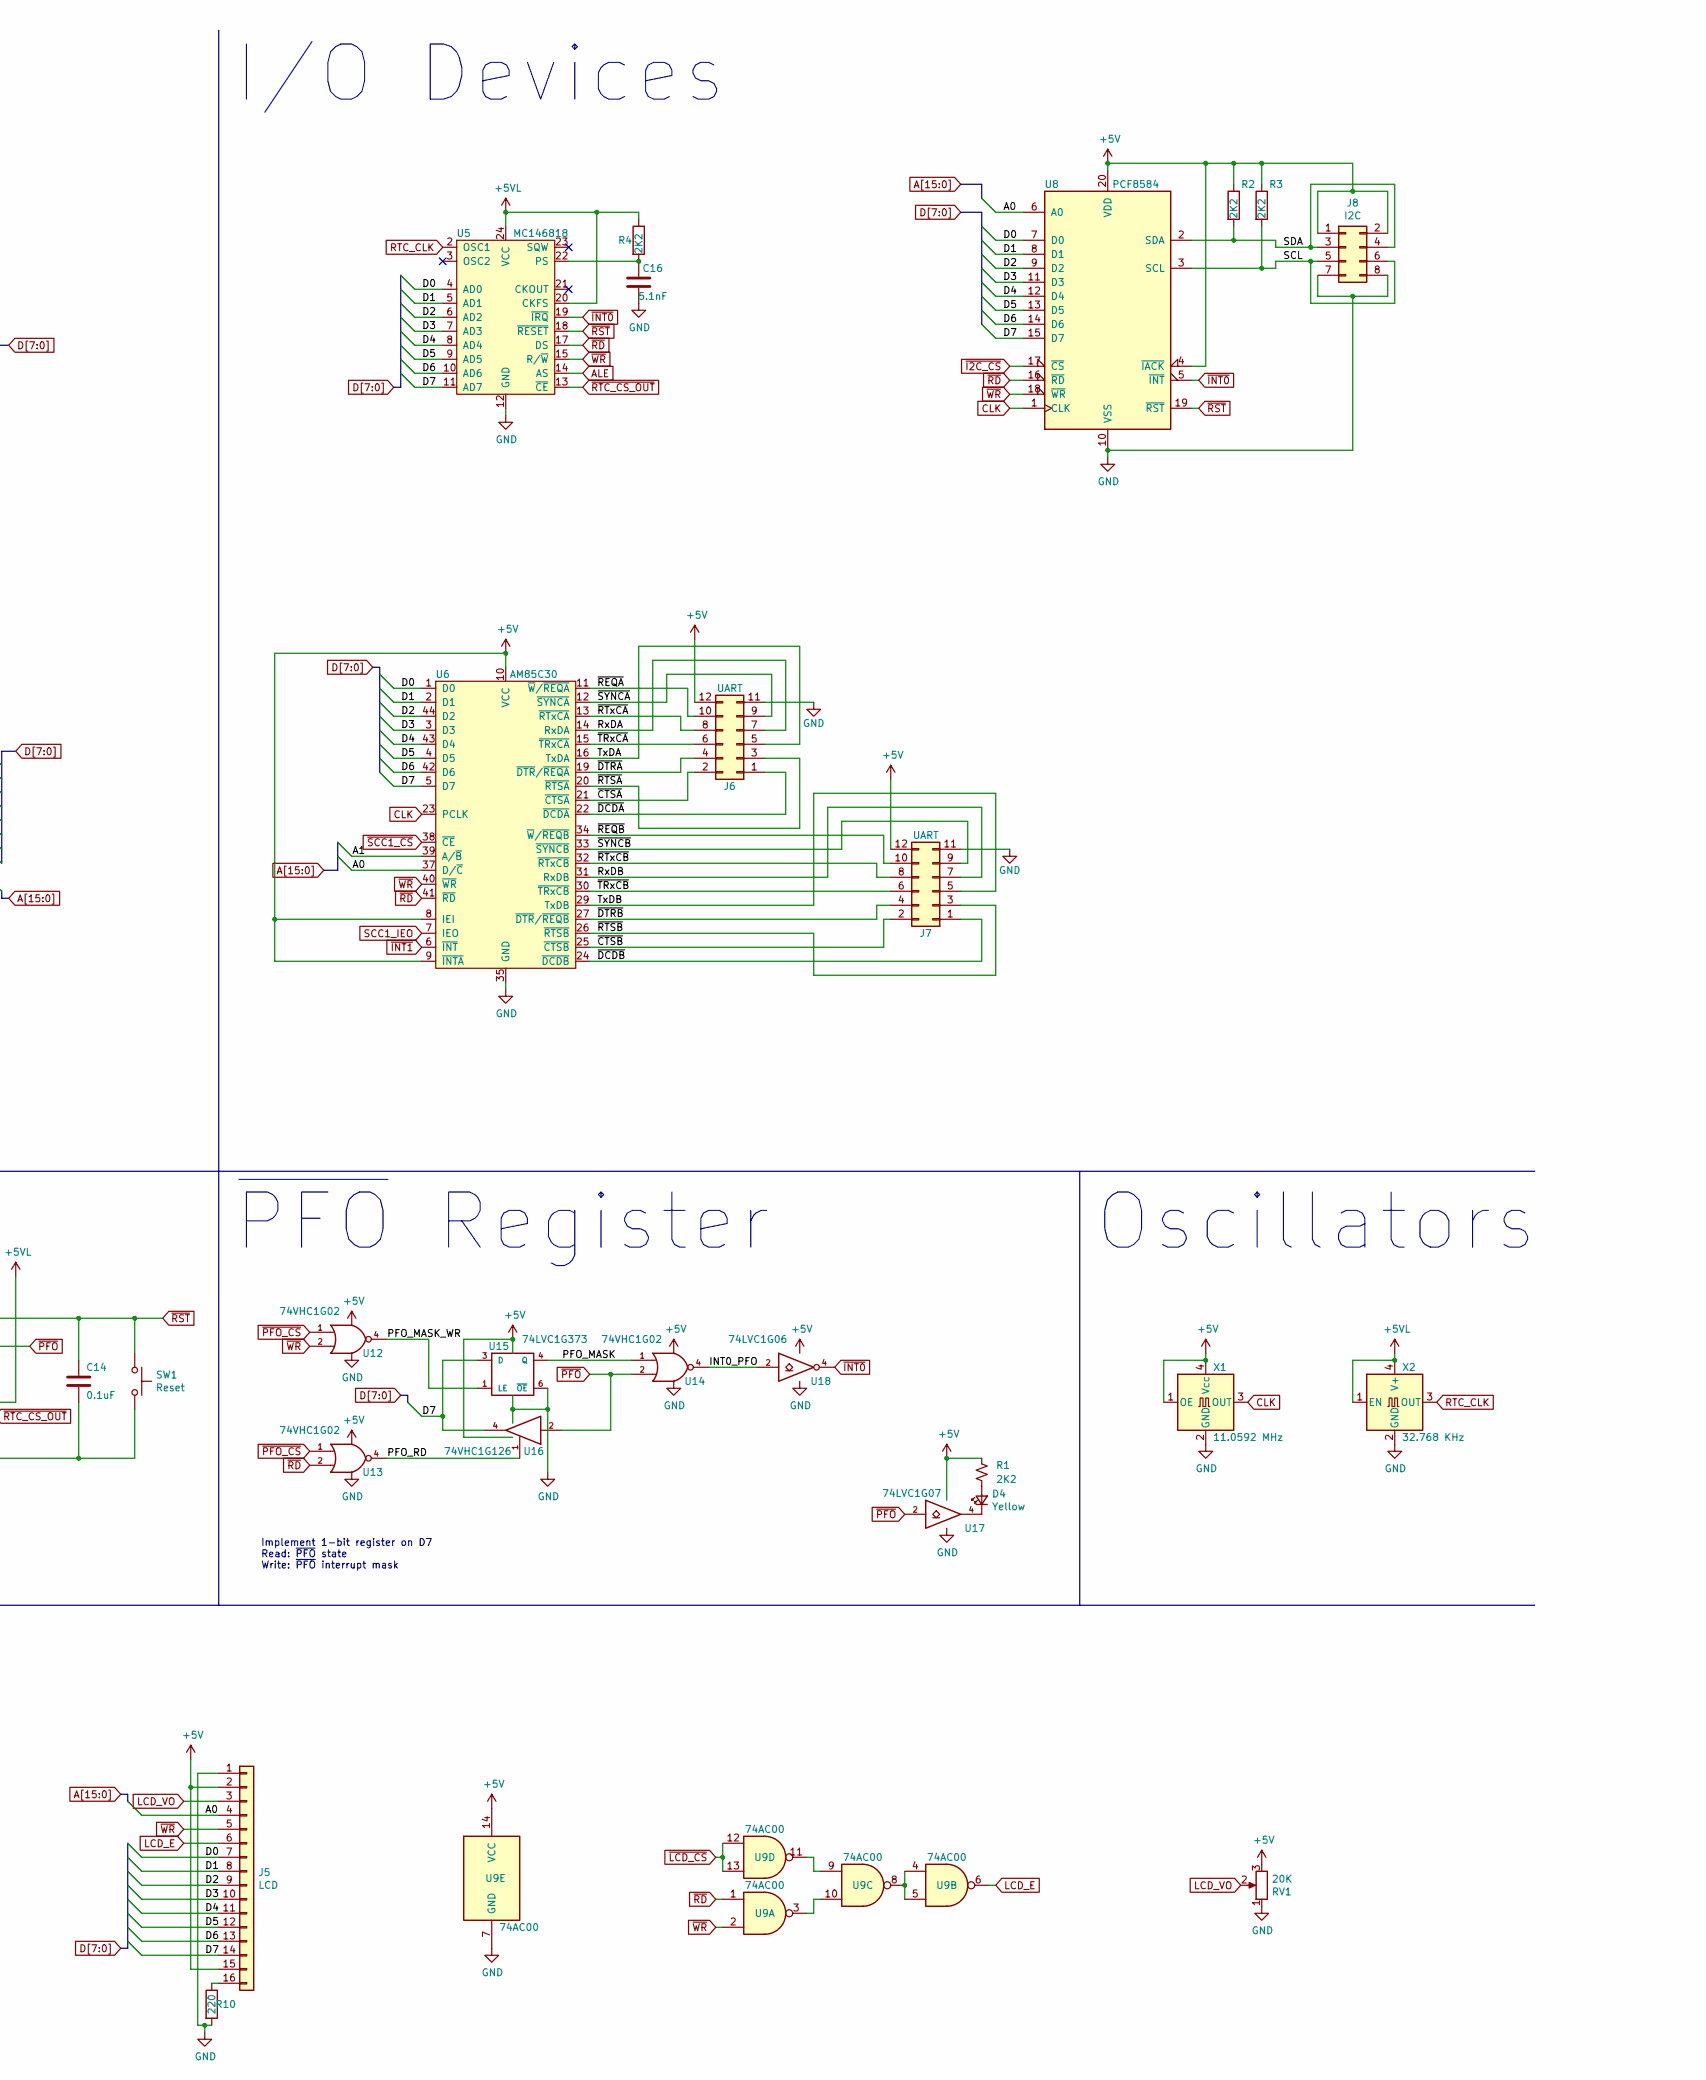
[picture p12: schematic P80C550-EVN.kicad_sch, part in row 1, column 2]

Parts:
BT1: RTC; BatteryHolder_Keystone_3001_1x12mm; Manufacturer_PN 3001; Digikey_PN 36-3001-ND‎
C1, C2, C3, C4, C5, C6, C7, C8, C9, C10, C11, C12, C13, C14, C15: 0.1uF; C_0603_1608Metric_Pad1.08x0.95mm_HandSolder; Manufacturer_PN C1608X7R1E104K080AA; Digikey_PN 445-1316-1-ND‎
C16: 5.1nF; C_0603_1608Metric_Pad1.08x0.95mm_HandSolder; Manufacturer_PN 06033C512JAT4A; Digikey_PN 478-06033C512JAT4ACT-ND
C17: 10uF; C_0805_2012Metric_Pad1.18x1.45mm_HandSolder; Manufacturer_PN TMK212BBJ106KG-T; Digikey_PN 587-2985-1-ND
C18: 22uF; C_0805_2012Metric_Pad1.18x1.45mm_HandSolder; Manufacturer_PN LMK212BBJ226MG-T; Digikey_PN 587-5464-1-ND
D1: 3.6V; D_SOT-23_ANK; Manufacturer_PN BZX84-C3V6,215; Digikey_PN 1727-5033-1-ND‎
D2: 5.1V; D_SOT-23_ANK; Manufacturer_PN BZX84-C5V1,235; Digikey_PN 1727-2130-1-ND‎
D3: Blue; LED_0603_1608Metric_Pad1.05x0.95mm_HandSolder; Manufacturer_PN IN-S63BT5B; Digikey_PN ‎1830-1068-1-ND‎
D4: Yellow; LED_0603_1608Metric_Pad1.05x0.95mm_HandSolder; Manufacturer_PN IN-S63BTR; Digikey_PN 1830-1072-1-ND‎
FB1: 100 @ 100 MHz; L_0603_1608Metric_Pad1.05x0.95mm_HandSolder; Manufacturer_PN FBMH1608HM101-T; Digikey_PN 587-1738-1-ND‎
H1, H2, H3, H4, H5, H6: MountingHole_Pad; MountingHole_3.5mm_Pad_LCD
J1: VIN; TerminalBlock_bornier-2_P5.08mm; Manufacturer_PN 34.102; Digikey_PN 1920-1323-ND
J2: Signals; PinSocket_2x05_P2.54mm_Vertical; Manufacturer_PN PPPC052LFBN-RC; Digikey_PN S7108-ND
J3: Address Low; PinSocket_1x13_P2.54mm_Vertical; Manufacturer_PN PPPC131LFBN-RC; Digikey_PN S7046-ND
J4: Address High; PinSocket_1x12_P2.54mm_Vertical; Manufacturer_PN PPPC131LFBN-RC; Digikey_PN S7046-ND
J5: LCD; PinSocket_1x16_P2.54mm_Vertical; Manufacturer_PN PPPC161LFBN-RC; Digikey_PN S7049-ND
J6, J7: UART; PinHeader_2x06_P2.54mm_Horizontal; Manufacturer_PN PRPC006DBAN-M71RC; Digikey_PN S2111EC-06-ND
J8: I2C; PinHeader_2x04_P2.54mm_Vertical; Manufacturer_PN PRPC004DAAN-RC; Digikey_PN S2011EC-04-ND
J9: Analog: In; PinHeader_1x08_P2.54mm_Vertical; Manufacturer_PN PRPC008SAAN-RC; Digikey_PN S1011EC-08-ND
J10: Analog: +5V; PinHeader_1x08_P2.54mm_Vertical; Manufacturer_PN PRPC008SAAN-RC; Digikey_PN S1011EC-08-ND
J11: Analog: GND; PinHeader_1x08_P2.54mm_Vertical; Manufacturer_PN PRPC008SAAN-RC; Digikey_PN S1011EC-08-ND
JP1: PFI Select; PinHeader_1x03_P1.27mm_Vertical_SMD_Pin1Left; Manufacturer_PN M50-3630342; Digikey_PN 952-3607-ND
L1: 39uH; L_0603_1608Metric_Pad1.05x0.95mm_HandSolder; Manufacturer_PN L-14C39NJV4T; Digikey_PN 712-1441-1-ND‎
L2: 4.7uH; L_1008_2520Metric_Pad1.43x2.20mm_HandSolder; Manufacturer_PN AIML-1008HC-4R7M-T; Digikey_PN 535-12797-1-ND
Q1: Si2393DS; SOT-23; Manufacturer_PN SI2393DS-T1-GE3; Digikey_PN ‎742-SI2393DS-T1-GE3CT-ND‎
Q2: BSS84; SOT-23; Manufacturer_PN BSS84; Digikey_PN BSS84CT-ND
R1, R2, R3, R4, R5, R6: 2K2; R_0603_1608Metric_Pad0.98x0.95mm_HandSolder; Manufacturer_PN CR0603-FX-2201ELF; Digikey_PN 118-CR0603-FX-2201ELFCT-ND‎
R7: 10K; R_0603_1608Metric_Pad0.98x0.95mm_HandSolder; Manufacturer_PN CR0603-FX-1002ELF; Digikey_PN CR0603-FX-1002ELFCT-ND
R8: 52K3; R_0603_1608Metric_Pad0.98x0.95mm_HandSolder; Manufacturer_PN CR0603-FX-5232ELF; Digikey_PN CR0603-FX-5232ELFCT-ND
R9: 680; R_0603_1608Metric_Pad0.98x0.95mm_HandSolder; Manufacturer_PN CR0603-JW-681ELF; Digikey_PN 118-CR0603-JW-681ELFCT-ND‎
R10: 220; R_Axial_DIN0207_L6.3mm_D2.5mm_P7.62mm_Horizontal
RV1, RV2: 20K; Potentiometer_Bourns_TC33X_Vertical; Manufacturer_PN TC33X-1-203E; Digikey_PN TC33X-1-203ECT-ND
SW1: Reset; SW_Tactile_SPST_Angled_PTS645Vx39-2LFS; Manufacturer_PN PTS645VM39-2 LFS; Digikey_PN CKN10909-ND
U1: P80C550EBAA; PLCC-44_THT-Socket
U2: 74AC573; DIP-20_W7.62mm_Socket; Manufacturer_PN CD74AC573E; Digikey_PN 296-1379-5-ND
U3: HM62256BLP; DIP-28_W15.24mm_Socket; Manufacturer_PN AS6C62256-55PCN; Digikey_PN AS6C62256-55PCN
U4: 28C256; DIP-28_W15.24mm_Socket; Manufacturer_PN AT28C256-15PU; Digikey_PN AT28C256-15PU-ND
U5: MC146818; DIP-24_W15.24mm_Socket
U6: AM85C30; PLCC-44_THT-Socket; Manufacturer_PN Z8523016VSG; Digikey_PN 269-3927-ND
U7: 74AHC138; DIP-16_W7.62mm_Socket; Manufacturer_PN CD74AC138E; Digikey_PN 296-4225-5-ND
U8: PCF8584; DIP-20_W7.62mm_Socket
U9: 74AC00; DIP-14_W7.62mm_Socket; Manufacturer_PN CD74AC00E; Digikey_PN 296-4214-5-ND
U10: MAX691xWE; SOIC-16W_7.5x10.3mm_P1.27mm
U11: AP62150WU; TSOT-23-6; Manufacturer_PN AP62150WU-7; Digikey_PN 31-AP62150WU-7CT-ND
U12, U13, U14: 74VHC1G02; TSOT-23-5_HandSoldering; Manufacturer_PN MC74VHC1G02DTT1G; Digikey_PN MC74VHC1G02DTT1GOSCT-ND‎
U15: 74LVC1G373; SOT-23-6_Handsoldering; Manufacturer_PN SN74LVC1G373DBVR; Digikey_PN 296-18588-1-ND‎
U16: 74VHC1G126; TSOT-23-5_HandSoldering; Manufacturer_PN M74VHC1G126DTT1G; Digikey_PN M74VHC1G126DTT1GOSCT-ND‎
U17: 74LVC1G07; SOT-353_SC-70-5_Handsoldering; Manufacturer_PN 74LVC1G07GW-Q100H; Digikey_PN 1727-1181-1-ND‎
U18: 74LVC1G06; SOT-353_SC-70-5_Handsoldering; Manufacturer_PN 74LVC1G06GW,125; Digikey_PN 1727-6064-1-ND‎
X1: 11.0592 MHz; Oscillator_SMD_SeikoEpson_SG8002CA-4Pin_7.0x5.0mm_HandSolde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; Manufacturer_PN SG7050CCN 11.059200M-HJGA3; Digikey_PN SER4011CT-ND‎
X2: 32.768 KHz; Oscillator_SMD_EuroQuartz_XO32-4Pin_3.2x2.5mm_HandSoldering; Manufacturer_PN ECS-327KE-TR; Digikey_PN XC1751CT-ND‎

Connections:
+5V: C1.1, C2.1, C3.1, C4.1, C5.1, C6.1, C7.1, C8.1, C9.1, C10.1, C18.1, J2.9, J3.2, J4.11, J5.2, J5.15, J6.12, J7.12, J8.1, J8.2, J10.1, J10.2, J10.3, J10.4, J10.5, J10.6, J10.7, J10.8, JP1.1 (A), L1.2, L2.2, Q2.2 (S), R1.1, R2.1, R3.1, R6.1, R8.1, RV1.3, U1.44 (VCC), U2.20 (VCC), U3.28 (VCC), U4.27 (~WE), U4.28 (VCC), U6.8 (IEI), U6.9 (~INTA), U6.10 (VCC), U7.16 (VCC), U8.4 (~IACK), U8.20 (VDD), U9.14 (VCC), U10.3 (VCC), U12.5 (VCC), U13.5 (VCC), U14.5 (VCC), U15.5 (VCC), U16.5 (VCC), U17.5 (VCC), U18.5 (VCC), X1.1 (OE), X1.4 (Vcc)
+5VA: C11.1, L1.1, R5.2, U1.1 (AVCC)
+5VL: C12.1, C13.1, R4.1, U5.20 (CKFS), U5.24 (VCC), U10.2 (VOUT), X2.1 (EN), X2.4 (V+)
+15V: C17.1, FB1.1, JP1.3 (B), U11.3 (IN)
/A0: J3.3, J5.4, U2.19 (Q0), U3.10 (A0), U4.10 (A0), U6.37 (D/~C), U8.6 (A0)
/A1: J3.4, U2.18 (Q1), U3.9 (A1), U4.9 (A1), U6.39 (A/~B)
/A2: J3.5, U2.17 (Q2), U3.8 (A2), U4.8 (A2)
/A3: J3.6, U2.16 (Q3), U3.7 (A3), U4.7 (A3)
/A4: J3.7, U2.15 (Q4), U3.6 (A4), U4.6 (A4)
/A5: J3.8, U2.14 (Q5), U3.5 (A5), U4.5 (A5)
/A6: J3.9, U2.13 (Q6), U3.4 (A6), U4.4 (A6)
/A7: J3.10, U2.12 (Q7), U3.3 (A7), U4.3 (A7)
/A8: J4.8, U1.25 (P2.0/A8), U3.25 (A8), U4.25 (A8)
/A9: J4.7, U1.26 (P2.1/A9), U3.24 (A9), U4.24 (A9)
/A10: J4.6, U1.27 (P2.2/A10), U3.21 (A10), U4.21 (A10), U7.1 (A0)
/A11: J4.5, U1.28 (P2.3/A11), U3.23 (A11), U4.23 (A11), U7.2 (A1)
/A12: J4.4, U1.29 (P2.4/A12), U3.2 (A12), U4.2 (A12), U7.3 (A2)
/A13: J4.3, U1.30 (P2.5/A13), U3.26 (A13), U4.26 (A13), U7.4 (E1)
/A14: J4.2, U1.31 (P2.6/A14), U3.1 (A14), U4.1 (A14), U7.5 (E2)
/A15: J4.1, U1.32 (P2.7/A15), U3.20 (~CS), U7.6 (E3)
/ADC0: J9.8, U1.5 (P1.0/ADC0)
/ADC1: J9.7, U1.6 (P1.1/ADC1)
/ADC2: J9.6, U1.7 (P1.2/ADC2)
/ADC3: J9.5, U1.8 (P1.3/ADC3)
/ADC4: J9.4, U1.9 (P1.4/ADC4)
/ADC5: J9.3, U1.10 (P1.5/ADC5)
/ADC6: J9.2, U1.11 (P1.6/ADC6)
/ADC7: J9.1, U1.12 (P1.7/ADC7)
/BST: C15.2, U11.6 (BST)
/D0: J5.7, U1.43 (P0.0/AD0), U2.2 (D0), U3.11 (Q0), U4.11 (D0), U5.4 (AD0), U6.1 (D0), U8.7 (D0)
/D1: J5.8, U1.42 (P0.1/AD1), U2.3 (D1), U3.12 (Q1), U4.12 (D1), U5.5 (AD1), U6.2 (D1), U8.8 (D1)
/D2: J5.9, U1.41 (P0.2/AD2), U2.4 (D2), U3.13 (Q2), U4.13 (D2), U5.6 (AD2), U6.44 (D2), U8.9 (D2)
/D3: J5.10, U1.40 (P0.3/AD3), U2.5 (D3), U3.15 (Q3), U4.15 (D3), U5.7 (AD3), U6.3 (D3), U8.11 (D3)
/D4: J5.11, U1.39 (P0.4/AD4), U2.6 (D4), U3.16 (Q4), U4.16 (D4), U5.8 (AD4), U6.43 (D4), U8.12 (D4)
/D5: J5.12, U1.38 (P0.5/AD5), U2.7 (D5), U3.17 (Q5), U4.17 (D5), U5.9 (AD5), U6.4 (D5), U8.13 (D5)
/D6: J5.13, U1.37 (P0.6/AD6), U2.8 (D6), U3.18 (Q6), U4.18 (D6), U5.10 (AD6), U6.42 (D6), U8.14 (D6)
/D7: J5.14, U1.36 (P0.7/AD7), U2.9 (D7), U3.19 (Q7), U4.19 (D7), U5.11 (AD7), U6.5 (D7), U8.15 (D7), U15.3 (D), U16.4
/FB: R7.1, R8.2, U11.4 (FB)
/INT0_PFO: U14.4, U18.2
/PFO_MASK: U14.1, U15.4 (Q)
/PFO_MASK_WR: U12.4, U15.1 (LE)
/PFO_RD: U13.4, U16.1
/Raw: J1.2, Q1.3 (D)
/RxDA: J6.7, U6.14 (RxDA)
/RxDB: J7.7, U6.31 (RxDB)
/SCL: J8.5, J8.6, R3.2, U8.3 (SCL)
/SDA: J8.3, J8.4, R2.2, U8.2 (SDA)
/SW: C15.1, L2.1, U11.2 (SW)
/TxDA: J6.5, U6.16 (TxDA)
/TxDB: J7.5, U6.29 (TxDB)
/VBATT: BT1.1 (+), U10.1 (VBATT)
/~CTSA: J6.2, U6.21 (~CTSA)
/~CTSB: J7.2, U6.25 (~CTSB)
/~DCDA: J6.1, U6.22 (~DCDA)
/~DCDB: J7.1, U6.24 (~DCDB)
/~DTRA: J6.4, U6.19 (~DTR/~REQA)
/~DTRB: J7.4, U6.27 (~DTR/~REQB)
/~REQA: J6.10, U6.11 (~W/~REQA)
/~REQB: J7.10, U6.34 (~W/~REQB)
/~RTSA: J6.3, U6.20 (~RTSA)
/~RTSB: J7.3, U6.26 (~RTSB)
/~RTxCA: J6.8, U6.13 (~RTxCA)
/~RTxCB: J7.8, U6.32 (~RTxCB)
/~SYNCA: J6.9, U6.12 (~SYNCA)
/~SYNCB: J7.9, U6.33 (~SYNCB)
/~TRxCA: J6.6, U6.15 (~TRxCA)
/~TRxCB: J7.6, U6.30 (~TRxCB)
ALE: U1.34 (ALE/~PROG), U2.11 (Load), U5.14 (AS)
CLK: J2.2, U1.23 (XTAL1), U6.23 (PCLK), U8.1 (CLK), X1.3 (OUT)
GND: BT1.2 (-), C1.2, C2.2, C3.2, C4.2, C5.2, C6.2, C7.2, C8.2, C9.2, C10.2, C11.2, C12.2, C13.2, C14.2, C16.1, C17.2, C18.2, D1.2 (A), D2.2 (A), D3.1 (K), H1.1, H2.1, H3.1, H4.1, H5.1, H6.1, J1.1, J2.10, J3.1, J4.12, J5.1, J6.11, J7.11, J8.7, J8.8, J11.1, J11.2, J11.3, J11.4, J11.5, J11.6, J11.7, J11.8, Q1.1 (G), R7.2, R9.2, R10.2, RV1.1, RV2.3, SW1.2, U1.3 (Vref-), U1.4 (AGND), U1.24 (GND), U1.35 (~EA/VPP), U2.1 (OE), U2.10 (GND), U3.14 (GND), U4.14 (GND), U5.12 (GND), U6.35 (GND), U7.8 (GND), U8.10 (VSS), U9.7 (GND), U10.4 (GND), U11.1 (GND), U12.3 (GND), U13.3 (GND), U14.3 (GND), U15.2 (GND), U15.6 (~OE), U16.3 (GND), U17.3 (GND), U18.3 (GND), X1.2 (GND), X2.2 (GND)
LCD_E: J5.6, U9.6
LCD_VO: J5.3, RV1.2
unnamed: C16.2, R4.2, U5.22 (PS)
unnamed: D3.2 (A), R6.2
unnamed: D4.1 (K), U17.4
unnamed: D4.2 (A), R1.2
unnamed: FB1.2, Q1.2 (S)
unnamed: J5.16, R10.1
unnamed: JP1.2 (C), RV2.1
unnamed: U9.4, U9.5, U9.8
unnamed: U9.3, U9.10
unnamed: U9.9, U9.11
PFI: D2.1 (K), RV2.2, U10.9 (PFI), U11.5 (EN)
RST: Q2.3 (D), U1.13 (RST)
RTC_CLK: U5.2 (OSC1), X2.3 (OUT)
RxD: J2.8, U1.14 (P3.0/RxD)
SCC1_IEO: J2.1, U6.7 (IEO)
T0: J2.3, U1.18 (P3.4/T0)
T1: J2.4, U1.19 (P3.5/T1)
TxD: J2.7, U1.15 (P3.1/TxD)
Vref+: D1.1 (K), R5.1, U1.2 (Vref+)
~CODE_CS: J3.12, R9.1, U4.20 (~CS)
~CODE_RD: J3.11, U1.33 (~PSEN), U4.22 (~OE)
~I2C_CS: U7.9 (O6), U8.17 (~CS)
~INT0: J2.6, U1.16 (P3.2/~INT0), U5.19 (~IRQ), U8.5 (~INT), U18.4
~INT1: J2.5, U1.17 (P3.3/~INT1), U6.6 (~INT)
~LCD_CS: U7.7 (O7), U9.12, U9.13
~PFO_CS: U7.15 (O0), U12.1, U13.1
~PFO: U10.10 (~PFO), U14.2, U16.2, U17.2
~RD: J4.10, U1.21 (P3.7/~RD), U3.22 (~OE), U5.17 (DS), U6.41 (~RD), U8.16 (~RD), U9.1, U13.2
~RST: C14.1, J3.13, Q2.1 (G), SW1.1, U5.18 (~RESET), U8.19 (~RST), U10.15 (~RESET)
~RTC_CS_OUT: U5.13 (~CE), U10.12 (~CE_OUT)
~RTC_CS: U7.11 (O4), U10.13 (~CE_IN)
~SCC1_CS: U6.38 (~CE), U7.10 (O5)
~WR: J4.9, J5.5, U1.20 (P3.6/~WR), U3.27 (~WE), U5.15 (R/~W), U6.40 (~WR), U8.18 (~WR), U9.2, U12.2

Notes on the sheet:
Memory
Memory Map 0000h ... 7FFFh: 32 KiB RAM 8000h ... 8000h: PFO Register 8400h ... 8FFFh: < empty > 9000h ... 903Fh: Real Time Clock 9400h ... 9403h: UART 9800h ... 9801h: I2C Controller 9C00h ... 9C01h: LCD A000h ... FFFFh: < empty >
CPU
RST pin on P80C550 has an internal pulldown of 50k to 300k ohms.
Oscillators
~{PFO} Register
I/O Devices
Implement 1-bit register on D7 Read: ~{PFO} state Write: ~{PFO} interrupt mask
Power
Expansion

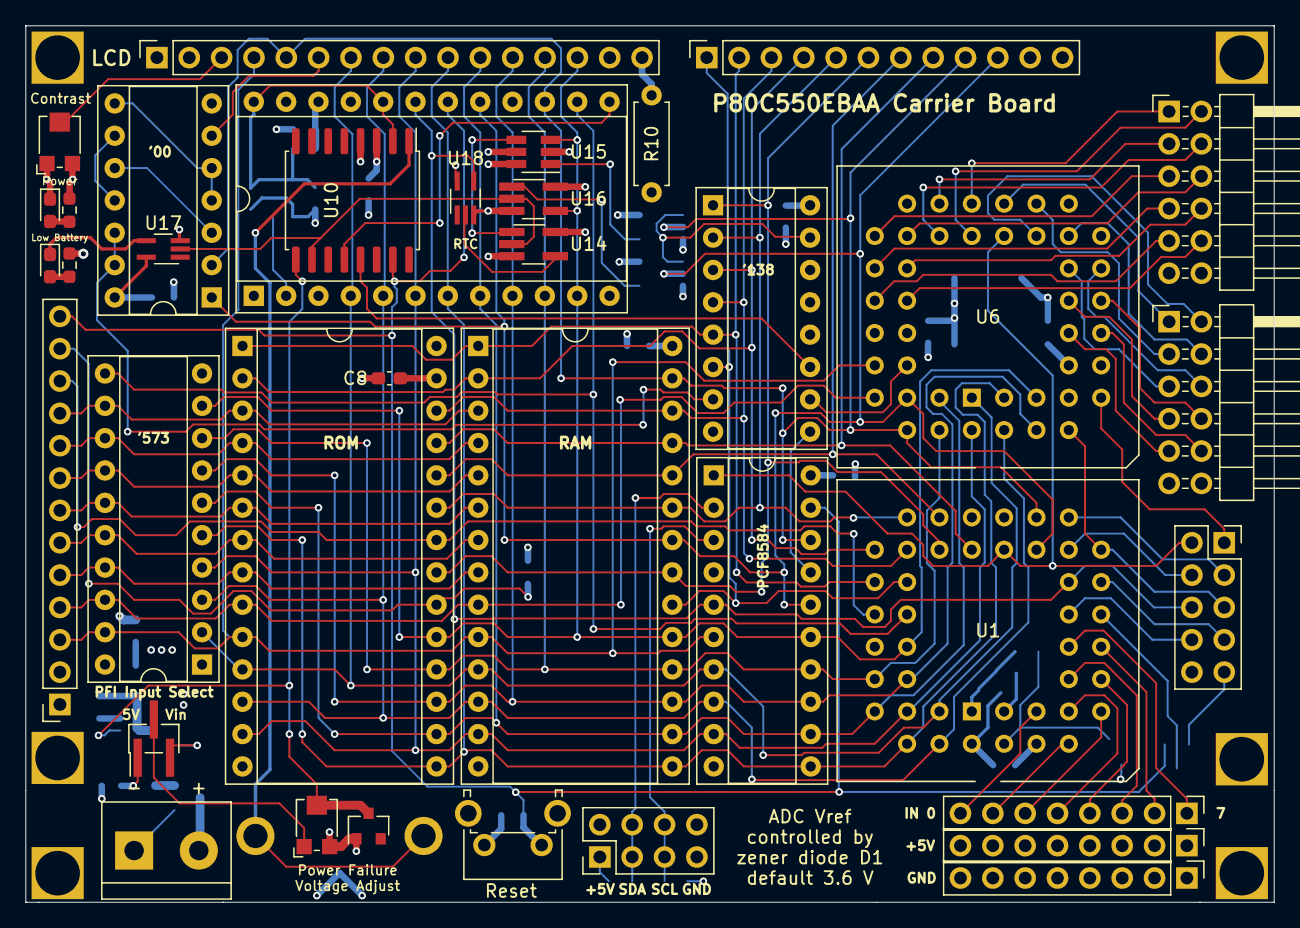
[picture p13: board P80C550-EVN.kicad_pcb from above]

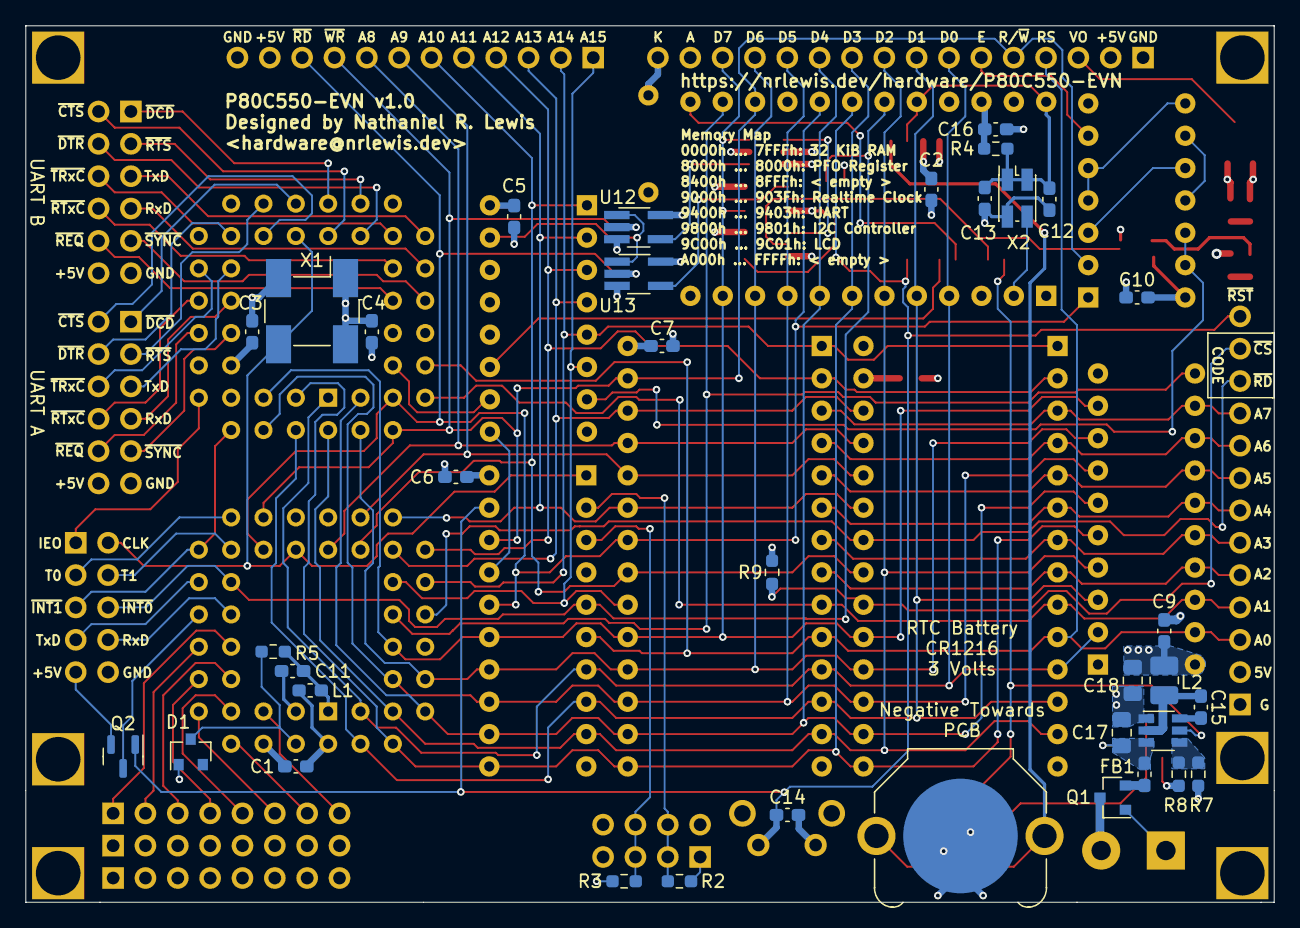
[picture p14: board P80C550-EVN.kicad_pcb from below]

Board: 4 copper layers, 98.0 x 68.8 mm, 79 parts (36 on the bottom side), 105 nets.

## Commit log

2021-05-02 project state for v1.0
    [P80C550-EVN-B_Cu.gbl, P80C550-EVN-B_Mask.gbs, P80C550-EVN-B_Paste.gbp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]
2021-07-22 reorganize gerbers and BOM
    [BOM.xlsx, P80C550-EVN-BOM.xlsx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]
2021-07-25 add pcb photos
2021-07-25 add photo of expansion connectors in use
2021-07-25 add schematic for v1.0
2023-01-13 update to KiCAD 6.x and fix the non-inverted reset signal by adding a P-Channel MOSFET to invert the inverted reset signal
    Fixes #1 and #2.
    [P80C550-EVN.kicad_pcb, P80C550-EVN.kicad_sch, P80C550-EVN.sch]
